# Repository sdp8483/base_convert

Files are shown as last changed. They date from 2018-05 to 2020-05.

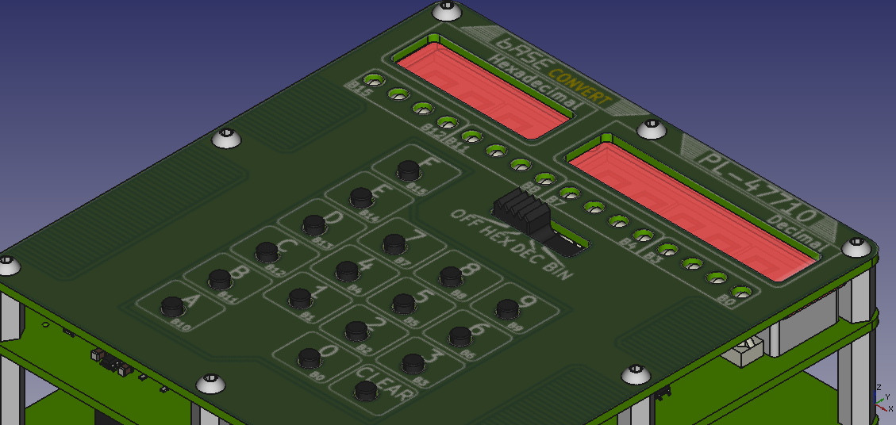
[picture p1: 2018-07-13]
main_pcb/pcb_renders/images/base_convert_assembly_top.png

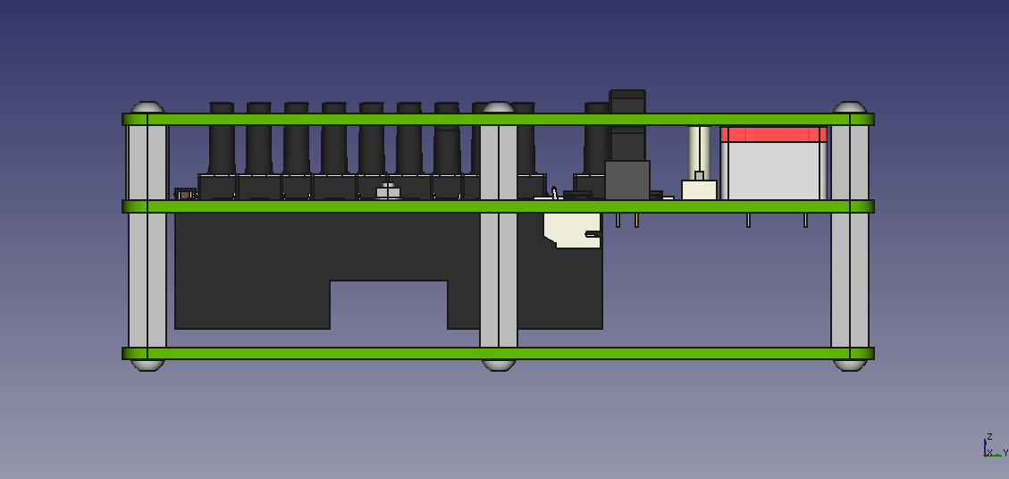
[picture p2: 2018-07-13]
main_pcb/pcb_renders/images/base_convert_assembly_side.png

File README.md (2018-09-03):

# Base Convert Rev A 
## Introduction
Base Convert PL-47710 Rev. A is a simple desk/handheld device to convert between hexadecimal, decimal, and binary. The unit features separate displays for each number base for easy comparison between the three bases. User input is possible using 16 alphanumeric keys and an input mode selector switch. The device is powered by 4 AA alkaline batteries with an estimated 100 hours of battery life.

## Specifications
|Item |Specification |
|:---|:---:|
|Hex Display |4 digit, 7 segment red LED  |
|Decimal Display  |6 digit, 7 segment red LED  |
|Binary Display |16 red LEDs |
|User Input |16 digit alphanumeric keypad|
|Power |4 AA Alkaline |
|Battery Life |100 hrs estimated |
|Width |94mm / 3.7" |
|Height |100mm / 3.94" |
|Thickness |35mm / 1.38" |
|Weight, with 4xAA|275g / 9.65oz |

## Layout
Front Layout Image

1. Hexadecimal Display
2. Decimal Display
3. Binary Display
4. Power and Input Selection Switch
5. Alphanumeric Input Keypad
6. Programming Port (Right Angle Header on Side)

## Installing Batteries
Using a 1.5mm hex bit remove the eight M2.5 button head hex bolts holding the back panel to the unit. Install 4x AA batteries into the battery holder attached to the main PCB. Follow the polarity imprinted on the battery holder. The device does have reverse polarity projection that should project it from damage but it is still advisable to not reverse the polarity of the batteries. Replace the back panel after installing the batteries.

## Use
To turn on the unit slide the selector switch from the OFF position to any of the three input positions. The display will illuminate at the default value of 0.

### To Input Hexadecimal Number
Slide the selector switch to *HEX*. The right most decimal on the hexadecimal display will illuminate when the unit is in hexadecimal input mode. Use the alphanumeric keypad to input a hexadecimal number, all three displays will update after each key press. If the hexadecimal number exceeds 4 digits the left most digit will be dropped to shift in the right most digit. Clearing the display by pressing the *CLEAR* button will set the hexadecimal number to 0.

### To Input Decimal Number
Slide the selector switch to *DEC*. The right most decimal on the decimal display will illuminate when the unit is in decimal input mode. Use the alphanumeric keypad to input a decimal number, all three displays will update after each key press. If the decimal number will exceed 65,535 with the requested key press the device will no longer shift in new decimal digits while in decimal input mode. Clearing the display will set the decimal number to 0.

### To Input Binary Number
Slide the selector switch to *BIN*. There is no indicator on any of the displays to indicate that the unit is in binary input mode. Use the alphanumeric keypad to toggle the bits of the binary number displayed on the binary display, all three displays will update after each key press. Pressing the *CLEAR* button will set the binary number to 0.

## Updating Firmware
It is possible to update the firmware. A TI Launchpad and cable is required. The pin out of the programming header is as follows when looking at the unit from the front.

- 3.3V
- SBWTDIO
- SBWTCK
- GND

External power is required, install 4x AA batteries before updating the firmware and place the selector switch in any of the input positions.

The most current firmware is located here: https://github.com/sdp8483/base_convert/tree/master/firmware/base_convert
CCS 8.x.x or newer is required to update the firmware. Please search online for help using CCS and uploading firmware since this is outside of the scope of this document.

## Future Fixes
- [ ] Silkscreen label of programming interface connections/pins
- [ ] Silkscreen label of power connector + and - pins
- [ ] add space for solder iron around resistor networks
- [ ] battery low indicator in SW, should have HW to do it
- [ ] at 6V the display will not turn off when the PNP are pulled high (cant pull it high enough) 
  Placing a 1k resistor between the base and emitter of each PNP solves the problem but it appears 
  like there is an issue caused with the 3.3V LDO since the voltage to the uC is 4.1V or so not the 3.3V it should be.
  Going to see if 3V for the battery is bright enough and maybe switch to 2AA as battery or go to LiPo in the future.
- [ ] Swap C2 and C4 on PCB so that the correct capacitor is near the correct IC
- [ ] Easy firmware update method --LOW PRIORITY

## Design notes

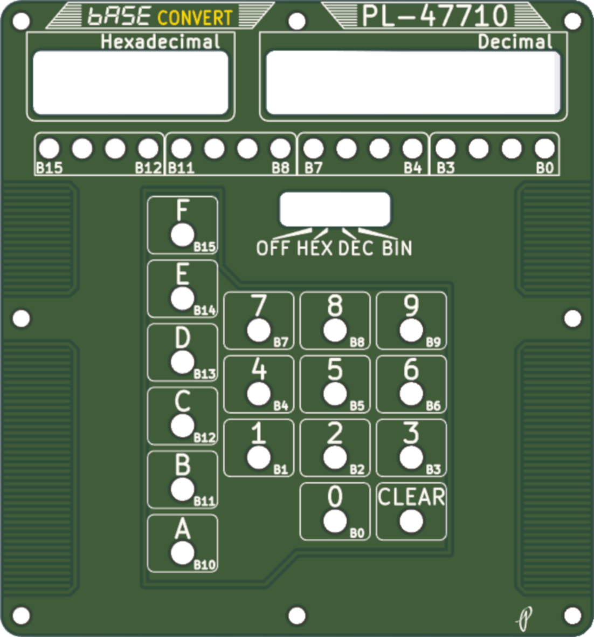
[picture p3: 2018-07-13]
front_panel_pcb/images/front_panel_pcb.png

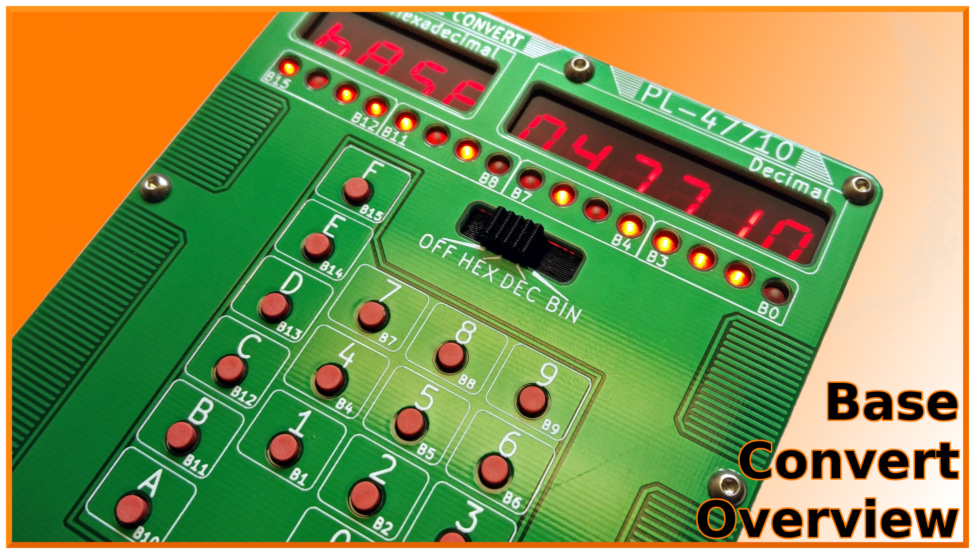
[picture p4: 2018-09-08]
images/Rev A/Tumbnail.jpg

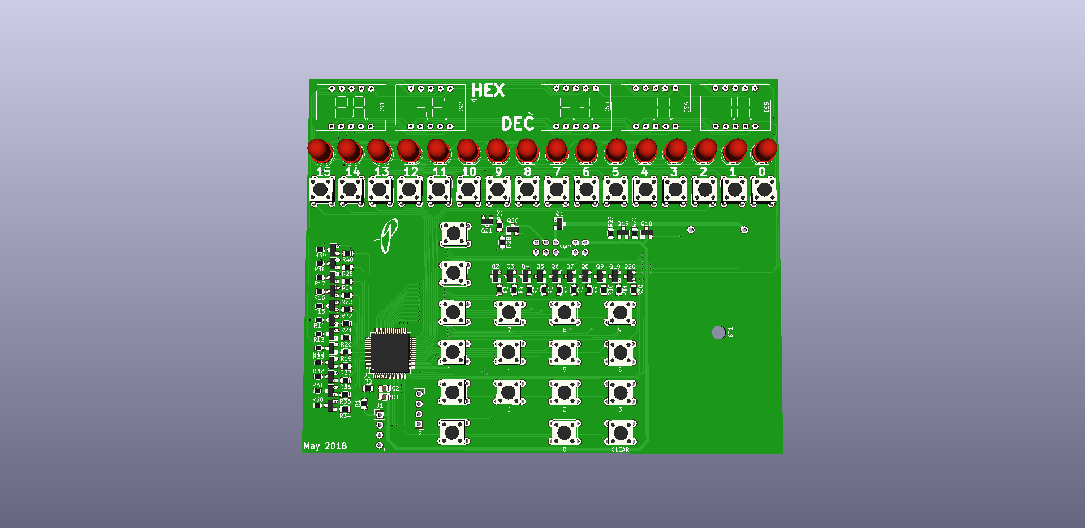
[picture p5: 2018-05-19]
images/base_convert_render2.png

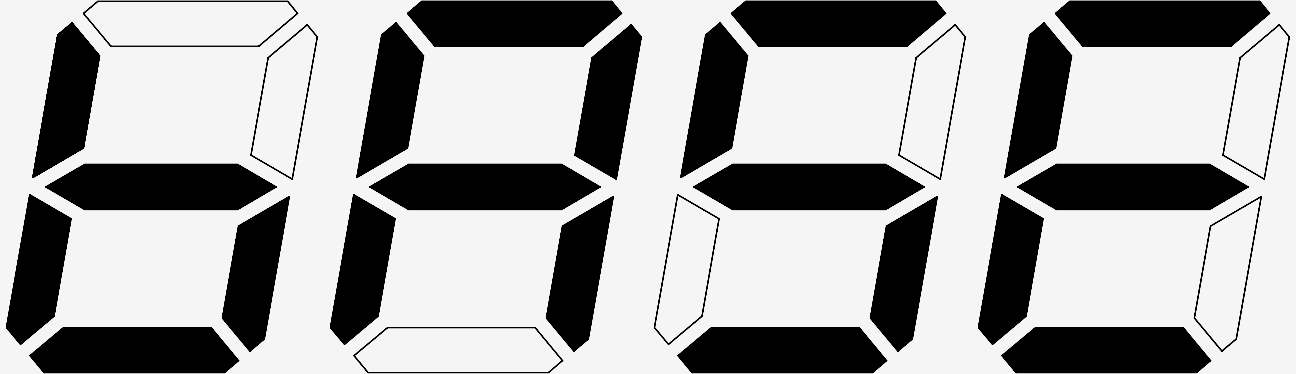
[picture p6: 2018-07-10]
front_panel_pcb/images/silkscreen_artwork/base_in_7seg_font.png

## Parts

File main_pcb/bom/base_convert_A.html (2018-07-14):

Source File | /Users/Sam/Documents/GitHub/base_convert/base_convert.sch
BoM Date | Saturday, July 14, 2018 'AMt' 07:05:44 AM
Schematic Version | A
Schematic Date | 2018-06-20
KiCad Version | Eeschema 4.0.7
Component Groups | 51
Component Count (per PCB) | 88
Fitted Components (per PCB) | 88
Number of PCBs | 1
Total Component Count (for 1 PCBs) | 88
 | Description | Part | References | Value | Footprint | Quantity Per PCB | Datasheet | Manufacture | Package | Mfg Part Number
1 | HOLDER BATT 4-AA CELLS WIRE LDS | BC4AAW | BT1 | 4 Cell AA Battery Clip | BC4AAW | 1 | http://www.memoryprotectiondevices.com/datasheets/BC4AAW-datasheet.pdf | MPD (Memory Protection Devices) | Wire | BC4AAW
2 | CAP CER 0.1UF 16V X7R 0805 | C | C3 | 100nF | C_0805 | 1 | http://www.samsungsem.com/kr/support/product-search/mlcc/CL21B104KOANNNC.jsp | Samsung Electro-Mechanics | 0805 | CL21B104KOANNNC
3 | CAP CER 10UF 6.3V X5R 0805 | C | C2 | 10uF | C_0805 | 1 | http://www.samsungsem.com/kr/support/product-search/mlcc/CL21A106KQFNNNG.jsp | Samsung Electro-Mechanics | 0805 | CL21A106KQFNNNG
4 | CAP CER 1UF 16V X7R 0805 | C | C1 C4 | 1uF | C_0805 | 2 | http://www.samsungsem.com/kr/support/product-search/mlcc/CL21B105KOFNNNG.jsp | Samsung Electro-Mechanics | 0805 | CL21B105KOFNNNG
5 | LED RED CLEAR 0805 SMD | LED | D13 | BIT0 | LED_0805_LightPipe_VLP | 1 | http://katalog.we-online.de/led/datasheet/150080RS75000.pdf | Wurth Electronics Inc. | 0805 | 150080RS75004
6 | LED RED CLEAR 0805 SMD | LED | D9 | BIT1 | LED_0805_LightPipe_VLP | 1 | http://katalog.we-online.de/led/datasheet/150080RS75000.pdf | Wurth Electronics Inc. | 0805 | 150080RS75015
7 | LED RED CLEAR 0805 SMD | LED | D7 | BIT10 | LED_0805_LightPipe_VLP | 1 | http://katalog.we-online.de/led/datasheet/150080RS75000.pdf | Wurth Electronics Inc. | 0805 | 150080RS75013
8 | LED RED CLEAR 0805 SMD | LED | D3 | BIT11 | LED_0805_LightPipe_VLP | 1 | http://katalog.we-online.de/led/datasheet/150080RS75000.pdf | Wurth Electronics Inc. | 0805 | 150080RS75009
9 | LED RED CLEAR 0805 SMD | LED | D16 | BIT12 | LED_0805_LightPipe_VLP | 1 | http://katalog.we-online.de/led/datasheet/150080RS75000.pdf | Wurth Electronics Inc. | 0805 | 150080RS75007
10 | LED RED CLEAR 0805 SMD | LED | D12 | BIT13 | LED_0805_LightPipe_VLP | 1 | http://katalog.we-online.de/led/datasheet/150080RS75000.pdf | Wurth Electronics Inc. | 0805 | 150080RS75003
11 | LED RED CLEAR 0805 SMD | LED | D8 | BIT14 | LED_0805_LightPipe_VLP | 1 | http://katalog.we-online.de/led/datasheet/150080RS75000.pdf | Wurth Electronics Inc. | 0805 | 150080RS75014
12 | LED RED CLEAR 0805 SMD | LED | D4 | BIT15 | LED_0805_LightPipe_VLP | 1 | http://katalog.we-online.de/led/datasheet/150080RS75000.pdf | Wurth Electronics Inc. | 0805 | 150080RS75010
13 | LED RED CLEAR 0805 SMD | LED | D5 | BIT2 | LED_0805_LightPipe_VLP | 1 | http://katalog.we-online.de/led/datasheet/150080RS75000.pdf | Wurth Electronics Inc. | 0805 | 150080RS75011
14 | LED RED CLEAR 0805 SMD | LED | D1 | BIT3 | LED_0805_LightPipe_VLP | 1 | http://katalog.we-online.de/led/datasheet/150080RS75000.pdf | Wurth Electronics Inc. | 0805 | 150080RS75000
15 | LED RED CLEAR 0805 SMD | LED | D14 | BIT4 | LED_0805_LightPipe_VLP | 1 | http://katalog.we-online.de/led/datasheet/150080RS75000.pdf | Wurth Electronics Inc. | 0805 | 150080RS75005
16 | LED RED CLEAR 0805 SMD | LED | D10 | BIT5 | LED_0805_LightPipe_VLP | 1 | http://katalog.we-online.de/led/datasheet/150080RS75000.pdf | Wurth Electronics Inc. | 0805 | 150080RS75001
17 | LED RED CLEAR 0805 SMD | LED | D6 | BIT6 | LED_0805_LightPipe_VLP | 1 | http://katalog.we-online.de/led/datasheet/150080RS75000.pdf | Wurth Electronics Inc. | 0805 | 150080RS75012
18 | LED RED CLEAR 0805 SMD | LED | D2 | BIT7 | LED_0805_LightPipe_VLP | 1 | http://katalog.we-online.de/led/datasheet/150080RS75000.pdf | Wurth Electronics Inc. | 0805 | 150080RS75008
19 | LED RED CLEAR 0805 SMD | LED | D15 | BIT8 | LED_0805_LightPipe_VLP | 1 | http://katalog.we-online.de/led/datasheet/150080RS75000.pdf | Wurth Electronics Inc. | 0805 | 150080RS75006
20 | LED RED CLEAR 0805 SMD | LED | D11 | BIT9 | LED_0805_LightPipe_VLP | 1 | http://katalog.we-online.de/led/datasheet/150080RS75000.pdf | Wurth Electronics Inc. | 0805 | 150080RS75002
21 | LED 7-SEG 2DIGIT RED LC 0.28" CA | LTD-2601WC | DS1 DS2 DS3 DS4 DS5 | LTD-2601WC | Display_Lite-On_LTD-2601WC | 5 | https://media.digikey.com/pdf/Data%20Sheets/Lite-On%20PDFs/LTD-2601WC_11-14-00.pdf | Lite-On Inc. | 10-DIP | LTD-2601WC
22 |  | Conn_01x04 | J1 | ISP | Pin_Header_Straight_1x04_Pitch2.54mm | 1
23 | CONN HEADER PH SIDE 2POS 2MM | Conn_01x02 | J3 | Vin | JST_PH_S2B-PH-K_02x2.00mm_Angled | 1 | http://www.jst-mfg.com/product/pdf/eng/ePH.pdf | JST Sales America Inc. | 2.0mm Pin | S2B-PH-K-S(LF)(SN)
24 | RES SMD 0 OHM JUMPER 1/4W 1206 | Jumper_NO_Small | JP1 | VTARG_EN | R_1206 | 1 | http://www.yageo.com/documents/recent/PYu-RC_Group_51_RoHS_L_9.pdf | Yageo | 1206 | RC1206JR-070RL
25 | TRANSISTOR, NPN, 40V, 0.2A, 100A | Q_NPN_BEC | Q6 Q7 Q8 Q9 Q20 Q21 Q22 Q23 Q24 Q25 Q26 Q27 | Q_NPN_BEC | SOT-23 | 12 | http://www.taiwansemi.com/products/datasheet/MMBT3904L_A15.pdf | Taiwan Semiconductor Corporation | SOT-23 | MMBT3904L RFG
26 | MOSFET P-CH 20V 5.3A SOT-23 | Q_PMOS_GSD | Q1 | Q_PMOS_GSD | SOT-23 | 1 | http://www.vishay.com/docs/64004/si2323dds.pdf | Vishay Siliconix | SOT-23 | SI2323DDS-T1-GE3
27 | TRANS PNP 40V 0.2A SOT23 | Q_PNP_BEC | Q2 Q3 Q4 Q5 Q10 Q11 Q12 Q13 Q14 Q15 Q16 Q17 Q18 Q19 | Q_PNP_BEC | SOT-23 | 14 | https://assets.nexperia.com/documents/data-sheet/PMBT3906.pdf | Nexperia USA Inc. | SOT-23 | PMBT3906,235
28 | RES SMD 102K OHM 1% 1/10W 0603 | R | R1 | 102k | R_0603 | 1 | http://rohmfs.rohm.com/en/products/databook/datasheet/passive/resistor/chip_resistor/mcr_g.pdf | Rohm Semiconductor | 0603 | MCR03ERTF1023
29 | RES SMD 25.5K OHM 1% 1/10W 0603 | R | R2 | 25.5k | R_0603 | 1 | http://rohmfs.rohm.com/en/products/databook/datasheet/passive/resistor/chip_resistor/mcr_g.pdf | Rohm Semiconductor | 0603 | MCR03ERTF2552
30 | RES ARRAY 4 RES 150 OHM 1206 | R_Pack04 | RN2 RN7 RN8 | 150 | R_Array_Convex_4x1206 | 3 | http://rohmfs.rohm.com/en/products/databook/datasheet/passive/resistor/chip_resistor_network/mnr_g.pdf | Rohm Semiconductor | 1206 | MNR14ERAPJ151
31 | RES ARRAY 4 RES 4.7K OHM 1206 | R_Pack04 | RN1 RN3 RN4 RN5 RN6 RN9 RN10 | 4.7k | R_Array_Convex_4x1206 | 7 | https://www.seielect.com/Catalog/SEI-RAVF.pdf | Stackpole Electronics Inc. | 1206 | RAVF164DJT4K70
32 | SWITCH TACTILE SPST-NO 0.05A 12V | SW_Push_Dual2 | SW9 | 0 | CK_PTS645_6mm_SMD | 1 | https://www.ckswitches.com/media/1471/pts645.pdf | C&K | SMT | PTS645SK13SMTR92LFS
33 | SWITCH TACTILE SPST-NO 0.05A 12V | SW_Push_Dual2 | SW10 | 1 | CK_PTS645_6mm_SMD | 1 | https://www.ckswitches.com/media/1471/pts645.pdf | C&K | SMT | PTS645SK13SMTR92LFS
34 | SWITCH TACTILE SPST-NO 0.05A 12V | SW_Push_Dual2 | SW6 | 2 | CK_PTS645_6mm_SMD | 1 | https://www.ckswitches.com/media/1471/pts645.pdf | C&K | SMT | PTS645SK13SMTR92LFS
35 | SWITCH TACTILE SPST-NO 0.05A 12V | SW_Push_Dual2 | SW2 | 3 | CK_PTS645_6mm_SMD | 1 | https://www.ckswitches.com/media/1471/pts645.pdf | C&K | SMT | PTS645SK13SMTR92LFS
36 | SWITCH TACTILE SPST-NO 0.05A 12V | SW_Push_Dual2 | SW11 | 4 | CK_PTS645_6mm_SMD | 1 | https://www.ckswitches.com/media/1471/pts645.pdf | C&K | SMT | PTS645SK13SMTR92LFS
37 | SWITCH TACTILE SPST-NO 0.05A 12V | SW_Push_Dual2 | SW7 | 5 | CK_PTS645_6mm_SMD | 1 | https://www.ckswitches.com/media/1471/pts645.pdf | C&K | SMT | PTS645SK13SMTR92LFS
38 | SWITCH TACTILE SPST-NO 0.05A 12V | SW_Push_Dual2 | SW3 | 6 | CK_PTS645_6mm_SMD | 1 | https://www.ckswitches.com/media/1471/pts645.pdf | C&K | SMT | PTS645SK13SMTR92LFS
39 | SWITCH TACTILE SPST-NO 0.05A 12V | SW_Push_Dual2 | SW12 | 7 | CK_PTS645_6mm_SMD | 1 | https://www.ckswitches.com/media/1471/pts645.pdf | C&K | SMT | PTS645SK13SMTR92LFS
40 | SWITCH TACTILE SPST-NO 0.05A 12V | SW_Push_Dual2 | SW8 | 8 | CK_PTS645_6mm_SMD | 1 | https://www.ckswitches.com/media/1471/pts645.pdf | C&K | SMT | PTS645SK13SMTR92LFS
41 | SWITCH TACTILE SPST-NO 0.05A 12V | SW_Push_Dual2 | SW4 | 9 | CK_PTS645_6mm_SMD | 1 | https://www.ckswitches.com/media/1471/pts645.pdf | C&K | SMT | PTS645SK13SMTR92LFS
42 | SWITCH TACTILE SPST-NO 0.05A 12V | SW_Push_Dual2 | SW13 | A | CK_PTS645_6mm_SMD | 1 | https://www.ckswitches.com/media/1471/pts645.pdf | C&K | SMT | PTS645SK13SMTR92LFS
43 | SWITCH TACTILE SPST-NO 0.05A 12V | SW_Push_Dual2 | SW15 | B | CK_PTS645_6mm_SMD | 1 | https://www.ckswitches.com/media/1471/pts645.pdf | C&K | SMT | PTS645SK13SMTR92LFS
44 | SWITCH TACTILE SPST-NO 0.05A 12V | SW_Push_Dual2 | SW16 | C | CK_PTS645_6mm_SMD | 1 | https://www.ckswitches.com/media/1471/pts645.pdf | C&K | SMT | PTS645SK13SMTR92LFS
45 | SWITCH TACTILE SPST-NO 0.05A 12V | SW_Push_Dual2 | SW14 | CLEAR | CK_PTS645_6mm_SMD | 1 | https://www.ckswitches.com/media/1471/pts645.pdf | C&K | SMT | PTS645SK13SMTR92LFS
46 | SWITCH TACTILE SPST-NO 0.05A 12V | SW_Push_Dual2 | SW17 | D | CK_PTS645_6mm_SMD | 1 | https://www.ckswitches.com/media/1471/pts645.pdf | C&K | SMT | PTS645SK13SMTR92LFS
47 | SWITCH TACTILE SPST-NO 0.05A 12V | SW_Push_Dual2 | SW18 | E | CK_PTS645_6mm_SMD | 1 | https://www.ckswitches.com/media/1471/pts645.pdf | C&K | SMT | PTS645SK13SMTR92LFS
48 | SWITCH TACTILE SPST-NO 0.05A 12V | SW_Push_Dual2 | SW5 | F | CK_PTS645_6mm_SMD | 1 | https://www.ckswitches.com/media/1471/pts645.pdf | C&K | SMT | PTS645SK13SMTR92LFS
49 | SWITCH SLIDE DP4T 300MA 30V | SS-24E06-TG5P | SW1 | SELECT | DP4T_SS-24E06-TG5P | 1 | https://media.digikey.com/pdf/Data%20Sheets/C&K/SS-24E06-TG_5_(P).pdf | C&K | PC Pin | SS-24E06-TG 5 (P)
50 | IC REG LINEAR 3.3V 150MA SOT23-5 | MIC5317 | U1 | MIC5317-3.3YM5-TR | SOT-23-5 | 1 | http://www.microchip.com/mymicrochip/filehandler.aspx?ddocname=en579427 | Microchip Technology | SOT23-5 | MIC5317-3.3YM5-TR
51 | IC MCU 16BIT 15.5KB FRAM 64LQFP | MSP430FR2033IPMR | U2 | MSP430FR2033IPMR | LQFP-64_10x10mm_Pitch0.5mm | 1 | http://www.ti.com/lit/ds/symlink/msp430fr2032.pdf | Texas Instruments | 64LQFP | MSP430FR2033IPMR

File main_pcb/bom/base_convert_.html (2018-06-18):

Source File | C:/Users/Sam/Dropbox/KiCAD/projects/base_convert/base_convert.sch
BoM Date | 6/18/2018 7:24:17 PM
Schematic Version
Schematic Date
KiCad Version | Eeschema 4.0.7
Component Groups | 51
Component Count (per PCB) | 116
Fitted Components (per PCB) | 116
Number of PCBs | 1
Total Component Count (for 1 PCBs) | 116
 | Description | Part | References | Value | Footprint | Quantity Per PCB | Datasheet | Manufacture | Package | Mfg Part Number
1 | HOLDER BATT 4-AA CELLS PC MNT | Battery | BT1 | 4 Cell AA Battery Holder | BC4AAPC | 1 | http://www.memoryprotectiondevices.com/datasheets/BC4AAPC-datasheet.pdf | MPD (Memory Protection Devices) | PC Pin | BC4AAPC
2 | CAP CER 0.1UF 16V X7R 0805 | C | C2 | 100nF | C_0805 | 1 | http://www.samsungsem.com/kr/support/product-search/mlcc/CL21B104KOANNNC.jsp | Samsung Electro-Mechanics | 0805 | CL21B104KOANNNC
3 | CAP CER 10UF 6.3V X5R 0805 | C | C1 | 10uF | C_0805 | 1 | http://www.samsungsem.com/kr/support/product-search/mlcc/CL21A106KQFNNNG.jsp | Samsung Electro-Mechanics | 0805 | CL21A106KQFNNNG
4 | CAP CER 1UF 16V X7R 0805 | C | C3 C4 | 1uF | C_0805 | 2 | http://www.samsungsem.com/kr/support/product-search/mlcc/CL21B105KOFNNNG.jsp | Samsung Electro-Mechanics | 0805 | CL21B105KOFNNNG
5 | LED RED CLEAR 0805 SMD | LED | D13 | BIT0 | LED_0805_LightPipe_VLP | 1 | http://katalog.we-online.de/led/datasheet/150080RS75000.pdf | Wurth Electronics Inc. | 0805 | 150080RS75004
6 | LED RED CLEAR 0805 SMD | LED | D9 | BIT1 | LED_0805_LightPipe_VLP | 1 | http://katalog.we-online.de/led/datasheet/150080RS75000.pdf | Wurth Electronics Inc. | 0805 | 150080RS75015
7 | LED RED CLEAR 0805 SMD | LED | D7 | BIT10 | LED_0805_LightPipe_VLP | 1 | http://katalog.we-online.de/led/datasheet/150080RS75000.pdf | Wurth Electronics Inc. | 0805 | 150080RS75013
8 | LED RED CLEAR 0805 SMD | LED | D3 | BIT11 | LED_0805_LightPipe_VLP | 1 | http://katalog.we-online.de/led/datasheet/150080RS75000.pdf | Wurth Electronics Inc. | 0805 | 150080RS75009
9 | LED RED CLEAR 0805 SMD | LED | D16 | BIT12 | LED_0805_LightPipe_VLP | 1 | http://katalog.we-online.de/led/datasheet/150080RS75000.pdf | Wurth Electronics Inc. | 0805 | 150080RS75007
10 | LED RED CLEAR 0805 SMD | LED | D12 | BIT13 | LED_0805_LightPipe_VLP | 1 | http://katalog.we-online.de/led/datasheet/150080RS75000.pdf | Wurth Electronics Inc. | 0805 | 150080RS75003
11 | LED RED CLEAR 0805 SMD | LED | D8 | BIT14 | LED_0805_LightPipe_VLP | 1 | http://katalog.we-online.de/led/datasheet/150080RS75000.pdf | Wurth Electronics Inc. | 0805 | 150080RS75014
12 | LED RED CLEAR 0805 SMD | LED | D4 | BIT15 | LED_0805_LightPipe_VLP | 1 | http://katalog.we-online.de/led/datasheet/150080RS75000.pdf | Wurth Electronics Inc. | 0805 | 150080RS75010
13 | LED RED CLEAR 0805 SMD | LED | D5 | BIT2 | LED_0805_LightPipe_VLP | 1 | http://katalog.we-online.de/led/datasheet/150080RS75000.pdf | Wurth Electronics Inc. | 0805 | 150080RS75011
14 | LED RED CLEAR 0805 SMD | LED | D1 | BIT3 | LED_0805_LightPipe_VLP | 1 | http://katalog.we-online.de/led/datasheet/150080RS75000.pdf | Wurth Electronics Inc. | 0805 | 150080RS75000
15 | LED RED CLEAR 0805 SMD | LED | D14 | BIT4 | LED_0805_LightPipe_VLP | 1 | http://katalog.we-online.de/led/datasheet/150080RS75000.pdf | Wurth Electronics Inc. | 0805 | 150080RS75005
16 | LED RED CLEAR 0805 SMD | LED | D10 | BIT5 | LED_0805_LightPipe_VLP | 1 | http://katalog.we-online.de/led/datasheet/150080RS75000.pdf | Wurth Electronics Inc. | 0805 | 150080RS75001
17 | LED RED CLEAR 0805 SMD | LED | D6 | BIT6 | LED_0805_LightPipe_VLP | 1 | http://katalog.we-online.de/led/datasheet/150080RS75000.pdf | Wurth Electronics Inc. | 0805 | 150080RS75012
18 | LED RED CLEAR 0805 SMD | LED | D2 | BIT7 | LED_0805_LightPipe_VLP | 1 | http://katalog.we-online.de/led/datasheet/150080RS75000.pdf | Wurth Electronics Inc. | 0805 | 150080RS75008
19 | LED RED CLEAR 0805 SMD | LED | D15 | BIT8 | LED_0805_LightPipe_VLP | 1 | http://katalog.we-online.de/led/datasheet/150080RS75000.pdf | Wurth Electronics Inc. | 0805 | 150080RS75006
20 | LED RED CLEAR 0805 SMD | LED | D11 | BIT9 | LED_0805_LightPipe_VLP | 1 | http://katalog.we-online.de/led/datasheet/150080RS75000.pdf | Wurth Electronics Inc. | 0805 | 150080RS75002
21 | LED 7-SEG .40" 2DGT SUPER RED CA | LTD-4608JR | DS1 DS2 DS3 DS4 DS5 | LTD-4608JR | Display_Lite-On_LTD-4608JR | 5 | https://media.digikey.com/pdf/Data%20Sheets/Lite-On%20PDFs/LTD-4608JR.pdf | Lite-On Inc. | 10-DIP | LTD-4608JR
22 |  | Conn_01x10 | J2 | DEBUG | Pin_Header_Straight_1x10_Pitch2.54mm | 1
23 |  | Conn_01x04 | J1 | ISP | Pin_Header_Straight_1x04_Pitch2.54mm | 1
24 | RES SMD 0 OHM JUMPER 1/4W 1206 | Jumper_NO_Small | JP1 | VTARG_EN | R_1206 | 1 | http://www.yageo.com/documents/recent/PYu-RC_Group_51_RoHS_L_9.pdf | Yageo | 1206 | RC1206JR-070RL
25 | TRANSISTOR, NPN, 40V, 0.2A, 100A | Q_NPN_BEC | Q11 Q12 Q13 Q14 Q15 Q16 Q17 Q22 Q23 Q24 Q25 Q27 | Q_NPN_BEC | SOT-23 | 12 | http://www.taiwansemi.com/products/datasheet/MMBT3904L_A15.pdf | Taiwan Semiconductor Corporation | SOT-23 | MMBT3904L RFG
26 | MOSFET P-CH 20V 5.3A SOT-23 | Q_PMOS_GSD | Q1 | Q_PMOS_GSD | SOT-23 | 1 | http://www.vishay.com/docs/64004/si2323dds.pdf | Vishay Siliconix | SOT-23 | SI2323DDS-T1-GE3
27 | TRANS PNP 40V 0.2A SOT25 | Q_PNP_BEC | Q2 Q3 Q4 Q5 Q6 Q7 Q8 Q9 Q10 Q18 Q19 Q20 Q21 Q26 | Q_PNP_BEC | SOT-23 | 14 | https://assets.nexperia.com/documents/data-sheet/PMBT3906.pdf | Nexperia USA Inc. | SOT-23 | PMBT3906,237 PMBT3906,235 PMBT3906,236 PMBT3906,238 PMBT3906,239 PMBT3906,240 PMBT3906,241
28 | RES SMD 102K OHM 1% 1/10W 0603 | R | R1 | 102k | R_0603 | 1 | http://rohmfs.rohm.com/en/products/databook/datasheet/passive/resistor/chip_resistor/mcr_g.pdf | Rohm Semiconductor | 0603 | MCR03ERTF1023
29 | RES SMD 150 OHM 5% 1/10W 0603 | R | R12 R13 R14 R15 R16 R17 R18 R30 R31 R32 R33 R39 | 150 | R_0603 | 12 | http://www.yageo.com/documents/recent/PYu-RC_Group_51_RoHS_L_9.pdf | Yageo | 0603 | RC0603JR-07150RL
30 | RES SMD 25.5K OHM 1% 1/10W 0603 | R | R2 | 25.5k | R_0603 | 1 | http://rohmfs.rohm.com/en/products/databook/datasheet/passive/resistor/chip_resistor/mcr_g.pdf | Rohm Semiconductor | 0603 | MCR03ERTF2552
31 | RES SMD 4.7K OHM 5% 1/10W 0603 | R | R3 R4 R5 R6 R7 R8 R9 R10 R11 R19 R20 R21 R22 R23 R24 R25 R26 R27 R28 R29 R34 R35 R36 R37 R38 R40 | 4.7k | R_0603 | 26 | http://industrial.panasonic.com/www-cgi/jvcr13pz.cgi?E+PZ+3+AOA0001+ERJ3GEYJ472V+7+WW | Panasonic Electronic Components | 0603 | ERJ-3GEYJ472V
32 | SWITCH TACTILE SPST-NO 0.05A 12V | SW_Push_Dual2 | SW19 | 0 | CK_PTS645_6mm_SMD | 1 | https://www.ckswitches.com/media/1471/pts645.pdf | C&K | SMT | PTS645SK95SMTR92LFS
33 | SWITCH TACTILE SPST-NO 0.05A 12V | SW_Push_Dual2 | SW23 | 1 | CK_PTS645_6mm_SMD | 1 | https://www.ckswitches.com/media/1471/pts645.pdf | C&K | SMT | PTS645SK95SMTR92LFS
34 | SWITCH TACTILE SPST-NO 0.05A 12V | SW_Push_Dual2 | SW27 | 2 | CK_PTS645_6mm_SMD | 1 | https://www.ckswitches.com/media/1471/pts645.pdf | C&K | SMT | PTS645SK95SMTR92LFS
35 | SWITCH TACTILE SPST-NO 0.05A 12V | SW_Push_Dual2 | SW31 | 3 | CK_PTS645_6mm_SMD | 1 | https://www.ckswitches.com/media/1471/pts645.pdf | C&K | SMT | PTS645SK95SMTR92LFS
36 | SWITCH TACTILE SPST-NO 0.05A 12V | SW_Push_Dual2 | SW20 | 4 | CK_PTS645_6mm_SMD | 1 | https://www.ckswitches.com/media/1471/pts645.pdf | C&K | SMT | PTS645SK95SMTR92LFS
37 | SWITCH TACTILE SPST-NO 0.05A 12V | SW_Push_Dual2 | SW24 | 5 | CK_PTS645_6mm_SMD | 1 | https://www.ckswitches.com/media/1471/pts645.pdf | C&K | SMT | PTS645SK95SMTR92LFS
38 | SWITCH TACTILE SPST-NO 0.05A 12V | SW_Push_Dual2 | SW28 | 6 | CK_PTS645_6mm_SMD | 1 | https://www.ckswitches.com/media/1471/pts645.pdf | C&K | SMT | PTS645SK95SMTR92LFS
39 | SWITCH TACTILE SPST-NO 0.05A 12V | SW_Push_Dual2 | SW32 | 7 | CK_PTS645_6mm_SMD | 1 | https://www.ckswitches.com/media/1471/pts645.pdf | C&K | SMT | PTS645SK95SMTR92LFS
40 | SWITCH TACTILE SPST-NO 0.05A 12V | SW_Push_Dual2 | SW21 | 8 | CK_PTS645_6mm_SMD | 1 | https://www.ckswitches.com/media/1471/pts645.pdf | C&K | SMT | PTS645SK95SMTR92LFS
41 | SWITCH TACTILE SPST-NO 0.05A 12V | SW_Push_Dual2 | SW25 | 9 | CK_PTS645_6mm_SMD | 1 | https://www.ckswitches.com/media/1471/pts645.pdf | C&K | SMT | PTS645SK95SMTR92LFS
42 | SWITCH TACTILE SPST-NO 0.05A 12V | SW_Push_Dual2 | SW29 | A | CK_PTS645_6mm_SMD | 1 | https://www.ckswitches.com/media/1471/pts645.pdf | C&K | SMT | PTS645SK95SMTR92LFS
43 | SWITCH TACTILE SPST-NO 0.05A 12V | SW_Push_Dual2 | SW33 | B | CK_PTS645_6mm_SMD | 1 | https://www.ckswitches.com/media/1471/pts645.pdf | C&K | SMT | PTS645SK95SMTR92LFS
44 | SWITCH TACTILE SPST-NO 0.05A 12V | SW_Push_Dual2 | SW22 | C | CK_PTS645_6mm_SMD | 1 | https://www.ckswitches.com/media/1471/pts645.pdf | C&K | SMT | PTS645SK95SMTR92LFS
45 | SWITCH TACTILE SPST-NO 0.05A 12V | SW_Push_Dual2 | SW1 | CLEAR | CK_PTS645_6mm_SMD | 1 | https://www.ckswitches.com/media/1471/pts645.pdf | C&K | SMT | PTS645SK95SMTR92LFS
46 | SWITCH TACTILE SPST-NO 0.05A 12V | SW_Push_Dual2 | SW26 | D | CK_PTS645_6mm_SMD | 1 | https://www.ckswitches.com/media/1471/pts645.pdf | C&K | SMT | PTS645SK95SMTR92LFS
47 | SWITCH TACTILE SPST-NO 0.05A 12V | SW_Push_Dual2 | SW30 | E | CK_PTS645_6mm_SMD | 1 | https://www.ckswitches.com/media/1471/pts645.pdf | C&K | SMT | PTS645SK95SMTR92LFS
48 | SWITCH TACTILE SPST-NO 0.05A 12V | SW_Push_Dual2 | SW34 | F | CK_PTS645_6mm_SMD | 1 | https://www.ckswitches.com/media/1471/pts645.pdf | C&K | SMT | PTS645SK95SMTR92LFS
49 | SWITCH SLIDE DP4T 300MA 30V | SS-24E06-TG5P | SW2 | SELECT | DP4T_SS-24E06-TG5P | 1 | https://media.digikey.com/pdf/Data%20Sheets/C&K/SS-24E06-TG_5_(P).pdf | C&K | PC Pin | SS-24E06-TG 5 (P)
50 | IC REG LINEAR 3.3V 150MA SOT23-5 | MIC5317 | U1 | MIC5317-3.3YM5-TR | SOT-23-5 | 1 | http://www.microchip.com/mymicrochip/filehandler.aspx?ddocname=en579427 | Microchip Technology | SOT23-5 | MIC5317-3.3YM5-TR
51 | IC MCU 16BIT 15.5KB FRAM 64LQFP | MSP430FR2033IPMR | U2 | MSP430FR2033IPMR | LQFP-64_10x10mm_Pitch0.5mm | 1 | http://www.ti.com/lit/ds/symlink/msp430fr2032.pdf | Texas Instruments | 64LQFP | MSP430FR2033IPMR

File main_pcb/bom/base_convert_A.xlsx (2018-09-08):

Description | References | Quantity Per PCB | Manufacture | Mfg Part Number | Supplier | Supplier Part Number | Purchased Qty | Price | Cost Per Unit | Cost Per PCB
HOLDER BATT 4-AA CELLS WIRE LDS | BT1 | 1 | MPD (Memory Protection Devices) | BC4AAW | DigiKey | BC4AAW-ND (https://www.digikey.com/product-detail/en/mpd-memory-protection-devices/BC4AAW/BC4AAW-ND/66733) | 6 | $10.98 | $1.83 | $1.83
CAP CER 0.1UF 16V X7R 0805 | C3 | 1 | Samsung Electro-Mechanics | CL21B104KOANNNC | DigiKey | 1276-2448-1-ND (https://www.digikey.com/product-detail/en/samsung-electro-mechanics/CL21B104KOANNNC/1276-2448-1-ND/3890534) | 500 | $4.43 | $0.01 | $0.01
CAP CER 10UF 6.3V X5R 0805 | C2 | 1 | Samsung Electro-Mechanics | CL21A106MQFNNNE | DigiKey | 1276-1298-1-ND (https://www.digikey.com/product-detail/en/samsung-electro-mechanics/CL21A106MQFNNNE/1276-1298-1-ND/3889384) | 100 | $4.62 | $0.05 | $0.05
CAP CER 1UF 16V X7R 0805 | C1 C4 | 2 | Samsung Electro-Mechanics | CL21B105KOFNNNG | DigiKey | 1276-6471-1-ND (https://www.digikey.com/product-detail/en/samsung-electro-mechanics/CL21B105KOFNNNG/1276-6471-1-ND/5958099) | 500 | $7.39 | $0.01 | $0.03
LED RED CLEAR 0805 SMD | D1-D16 | 16 | Wurth Electronics Inc. | 150080RS75000 | DigiKey | 732-4984-1-ND (https://www.digikey.com/product-detail/en/wurth-electronics-inc/150080RS75000/732-4984-1-ND/4489916) | 160 | $21.92 | $0.14 | $2.19
LED 7-SEG 2DIGIT RED LC 0.28" CA | DS1 DS2 DS3 DS4 DS5 | 5 | Lite-On Inc. | LTD-2601WC | DigiKey | 160-2244-ND (https://www.digikey.com/product-detail/en/lite-on-inc/LTD-2601WC/160-2244-ND/3199017) | 35 | $53.10 | $1.52 | $7.59
4POS SIL HORIZONTAL PIN HEADER | J1 | 1 | Harwin Inc. | M20-9750446 | DigiKey | 952-1965-ND | 1 | $0.18 | $0.18 | $0.18
CONN HEADER PH SIDE 2POS 2MM | J3 | 1 | JST Sales America Inc. | S2B-PH-K-S(LF)(SN) | DigiKey | 455-1719-ND (https://www.digikey.com/product-detail/en/jst-sales-america-inc/S2B-PH-K-S(LF)(SN)/455-1719-ND/926626) | 10 | $1.61 | $0.16 | $0.16
CONN HOUSING PH 2POS 2MM WHITE |  | 1 | JST Sales America Inc. | PHR-2 | DigiKey | 455-1165-ND (https://www.digikey.com/product-detail/en/jst-sales-america-inc/PHR-2/455-1165-ND/608607) | 10 | $0.78 | $0.08 | $0.08
CONN TERMINAL 28-24AWG TIN |  | 2 | JST Sales America Inc. | SPH-002T-P0.5L | DigiKey | 455-2148-1-ND (https://www.digikey.com/product-detail/en/jst-sales-america-inc/SPH-002T-P0.5L/455-2148-1-ND/1634657) | 100 | $2.99 | $0.03 | $0.06
RES SMD 0 OHM JUMPER 1/4W 1206 | JP1 | 0 | Yageo | RC1206JR-070RL | DigiKey | 311-0.0ERCT-ND (https://www.digikey.com/product-detail/en/yageo/RC1206JR-070RL/311-0.0ERCT-ND/732131) | 1000 | $4.35 | $0.00435 | $0.00
TRANSISTOR, NPN, 40V, 0.2A, 100A | Q6 Q7 Q8 Q9 Q20 Q21 Q22 Q23 Q24 Q25 Q26 Q27 | 12 | Taiwan Semiconductor Corporation | MMBT3904L RFG | DigiKey | MMBT3904LRFGCT-ND (https://www.digikey.com/product-detail/en/taiwan-semiconductor-corporation/MMBT3904L-RFG/MMBT3904LRFGCT-ND/7357839) | 200 | $10.14 | $0.05 | $0.61
MOSFET P-CH 20V 5.3A SOT-23 | Q1 | 1 | Vishay Siliconix | SI2323DDS-T1-GE3 | DigiKey | SI2323DDS-T1-GE3CT-ND (https://www.digikey.com/product-detail/en/vishay-siliconix/SI2323DDS-T1-GE3/SI2323DDS-T1-GE3CT-ND/4142086) | 10 | $6.05 | $0.60 | $0.60
TRANS PREBIAS PNP 250MW TO236AB | Q2 Q3 Q4 Q5 Q10 Q11 Q12 Q13 Q14 Q15 Q16 Q17 Q18 Q19 | 14 | Nexperia USA Inc. | PDTA123ET,215 | DigiKey | 1727-1691-1-ND (https://www.digikey.com/product-detail/en/nexperia-usa-inc/PDTA123ET,215/1727-1691-1-ND/4581217) | 20 | $3.36 | $0.17 | $2.35
RES SMD 102K OHM 1% 1/10W 0603 | R1 | 1 | Rohm Semiconductor | MCR03ERTF1023 | DigiKey | RHM102KCFCT-ND (https://www.digikey.com/product-detail/en/rohm-semiconductor/MCR03ERTF1023/RHM102KCFCT-ND/4083896) | 2500 | $4.24 | $0.001696 | $0.001696
RES SMD 25.5K OHM 1% 1/10W 0603 | R2 | 1 | Rohm Semiconductor | MCR03ERTF2552 | DigiKey | RHM25.5KCFCT-ND (https://www.digikey.com/product-detail/en/rohm-semiconductor/MCR03ERTF2552/RHM25.5KCFCT-ND/4084087) | 408 | $1.75 | $0.004289215686 | $0.004289215686
RES ARRAY 4 RES 150 OHM 2012 | RN2 RN7 RN8 | 3 | Rohm Semiconductor | MNR34J5ABJ151 | DigiKey | MNR34151CT-ND (https://www.digikey.com/product-detail/en/rohm-semiconductor/MNR34J5ABJ151/MNR34151CT-ND/657596) | 30 | $5.39 | $0.18 | $0.54
RES ARRAY 4 RES 5.6K OHM 2012 | RN3 RN9 RN10 | 3 | Rohm Semiconductor | MNR34J5ABJ562 | DigiKey | MNR34562CT-ND (https://www.digikey.com/product-detail/en/rohm-semiconductor/MNR34J5ABJ562/MNR34562CT-ND/657638) | 50 | $6.51 | $0.13 | $0.39
RES ARRAY 4 RES 10K OHM 2012 | RN1 RN4 RN5 RN6 | 4 | Yageo | YC324-JK-0710KL | DigiKey | YC324J-10KCT-ND (https://www.digikey.com/product-detail/en/yageo/YC324-JK-0710KL/YC324J-10KCT-ND/1005865) | 50 | $7.97 | $0.16 | $0.64
SWITCH TACTILE SPST-NO 0.05A 12V | SW2-SW18 | 17 | C&K | PTS645SK13SMTR92LFS | DigiKey | CKN10817CT-ND (https://www.digikey.com/product-detail/en/c-k/PTS645SK13SMTR92LFS/CKN10817CT-ND/7056128) | 118 | $34.00 | $0.29 | $4.90
SWITCH SLIDE DP4T 300MA 30V | SW1 | 1 | C&K | SS-24E06-TG 5 (P) | DigiKey | CKN10394-ND (https://www.digikey.com/product-detail/en/c-k/SS-24E06-TG-5-(P)/CKN10394-ND/2747191) | 9 | $7.56 | $0.84 | $0.84
IC REG LINEAR 3.3V 150MA SOT23-5 | U1 | 1 | Microchip Technology | MIC5317-3.3YM5-TR | DigiKey | MIC5317-3.3YM5-CT-ND (https://www.digikey.com/product-detail/en/microchip-technology/MIC5317-3.3YM5-TR/MIC5317-3.3YM5-CT-ND/7671939) | 50 | $6.70 | $0.13 | $0.13
IC MCU 16BIT 15.5KB FRAM 64LQFP | U2 | 1 | Texas Instruments | MSP430FR2033IPMR | DigiKey | 296-48617-1-ND (https://www.digikey.com/product-detail/en/texas-instruments/MSP430FR2033IPMR/296-48617-1-ND/8567661) | 7 | $18.20 | $2.60 | $2.60
LIGHT PIPE VERTICAL .450" ROUND |  | 16 | Bivar Inc. | VLP-450-R | DigiKey | 492-1347-ND (https://www.digikey.com/product-detail/en/bivar-inc/VLP-450-R/492-1347-ND/586475) | 100 | $29.23 | $0.29 | $4.68
HEX STNDFF M2.5X0.45 STEEL 10MM |  | 8 | Wurth Electronics Inc. | 971100151 | DigiKey | 732-10397-ND (https://www.digikey.com/product-detail/en/wurth-electronics-inc/971100151/732-10397-ND/6174616) | 50 | $19.80 | $0.40 | $3.17
HEX SPACER M2.5X0.45 STEEL 18MM |  | 8 | Wurth Electronics Inc. | 970180151 | DigiKey | 732-10586-ND (https://www.digikey.com/product-detail/en/wurth-electronics-inc/970180151/732-10586-ND/6174806) | 50 | $22.88 | $0.46 | $3.66
LED Display Lens |  | 2 | Hammond Manufacturing | 1593SIR10 | DigiKey | HM889-ND (https://www.digikey.com/product-detail/en/hammond-manufacturing/1593SIR10/HM889-ND/409899) | 5 | $2.58 | $0.52 | $1.03
BASE CONVERT MAIN PCB |  | 1 | JLCPCB |  | JLCPCB |  | 10 | $12.19 | $1.22 | $1.22
BASE CONVERT FRONT PCB |  | 1 | JLCPCB |  | JLCPCB |  | 10 | $9.19 | $0.92 | $0.92
BASE CONVERT BACK PCB |  | 1 | JLCPCB |  | JLCPCB |  | 10 | $12.19 | $1.22 | $1.22
Button Head Hex Drive Screw M2.5 x 5mm Long |  | 16 | McMaster-Carr | 94500A212 | McMaster-Carr |  | 100 | $11.66 | $0.12 | $1.87
Flat Head Phillips M1.6 x 6mm Long |  | 2 | McMaster-Carr | 92010A782 | McMaster-Carr |  | 100 | $8.58 | $0.09 | $0.17
Hex Nut M1.6 x 0.35mm |  | 2 | McMaster-Carr | 90591A109 | McMaster-Carr |  | 50 | $8.76 | $0.18 | $0.35
Washer M1.6 |  | 2 | McMaster-Carr | 93475A190 | McMaster-Carr |  | 100 | $2.27 | $0.02 | $0.05
 |  |  |  |  |  |  |  |  |  | $44.11
Build Cost | $44.11
Markup Multiplyier | 2.5
Selling Price | $110.27
Shipping Cost | $3.68
Total Cost To Customer | $113.95
Tindie Fee 5% | $5.70
Payment Processing Fee 4% + $0.3 | $4.86
Tindie Dispersment | $103.40
Profit | $59.29

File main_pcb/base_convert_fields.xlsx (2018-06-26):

Refs | Description | Manufacture | Mfg Part Number | Package | datasheet | footprint | value
BT1 | HOLDER BATT 4-AA CELLS WIRE LDS | MPD (Memory Protection Devices) | BC4AAW | Wire | http://www.memoryprotectiondevices.com/datasheets/BC4AAW-datasheet.pdf | MPD:BC4AAW | 4 Cell AA Battery Clip
C1 | CAP CER 1UF 16V X7R 0805 | Samsung Electro-Mechanics | CL21B105KOFNNNG | 0805 | http://www.samsungsem.com/kr/support/product-search/mlcc/CL21B105KOFNNNG.jsp | Capacitors_SMD:C_0805 | 1uF
C2 | CAP CER 10UF 6.3V X5R 0805 | Samsung Electro-Mechanics | CL21A106KQFNNNG | 0805 | http://www.samsungsem.com/kr/support/product-search/mlcc/CL21A106KQFNNNG.jsp | Capacitors_SMD:C_0805 | 10uF
C3 | CAP CER 0.1UF 16V X7R 0805 | Samsung Electro-Mechanics | CL21B104KOANNNC | 0805 | http://www.samsungsem.com/kr/support/product-search/mlcc/CL21B104KOANNNC.jsp | Capacitors_SMD:C_0805 | 100nF
C4 | CAP CER 1UF 16V X7R 0805 | Samsung Electro-Mechanics | CL21B105KOFNNNG | 0805 | http://www.samsungsem.com/kr/support/product-search/mlcc/CL21B105KOFNNNG.jsp | Capacitors_SMD:C_0805 | 1uF
D1 | LED RED CLEAR 0805 SMD | Wurth Electronics Inc. | 150080RS75000 | 0805 | http://katalog.we-online.de/led/datasheet/150080RS75000.pdf | LightPipe_Bivar:LED_0805_LightPipe_VLP | BIT3
D10 | LED RED CLEAR 0805 SMD | Wurth Electronics Inc. | 150080RS75001 | 0805 | http://katalog.we-online.de/led/datasheet/150080RS75000.pdf | LightPipe_Bivar:LED_0805_LightPipe_VLP | BIT5
D11 | LED RED CLEAR 0805 SMD | Wurth Electronics Inc. | 150080RS75002 | 0805 | http://katalog.we-online.de/led/datasheet/150080RS75000.pdf | LightPipe_Bivar:LED_0805_LightPipe_VLP | BIT9
D12 | LED RED CLEAR 0805 SMD | Wurth Electronics Inc. | 150080RS75003 | 0805 | http://katalog.we-online.de/led/datasheet/150080RS75000.pdf | LightPipe_Bivar:LED_0805_LightPipe_VLP | BIT13
D13 | LED RED CLEAR 0805 SMD | Wurth Electronics Inc. | 150080RS75004 | 0805 | http://katalog.we-online.de/led/datasheet/150080RS75000.pdf | LightPipe_Bivar:LED_0805_LightPipe_VLP | BIT0
D14 | LED RED CLEAR 0805 SMD | Wurth Electronics Inc. | 150080RS75005 | 0805 | http://katalog.we-online.de/led/datasheet/150080RS75000.pdf | LightPipe_Bivar:LED_0805_LightPipe_VLP | BIT4
D15 | LED RED CLEAR 0805 SMD | Wurth Electronics Inc. | 150080RS75006 | 0805 | http://katalog.we-online.de/led/datasheet/150080RS75000.pdf | LightPipe_Bivar:LED_0805_LightPipe_VLP | BIT8
D16 | LED RED CLEAR 0805 SMD | Wurth Electronics Inc. | 150080RS75007 | 0805 | http://katalog.we-online.de/led/datasheet/150080RS75000.pdf | LightPipe_Bivar:LED_0805_LightPipe_VLP | BIT12
D2 | LED RED CLEAR 0805 SMD | Wurth Electronics Inc. | 150080RS75008 | 0805 | http://katalog.we-online.de/led/datasheet/150080RS75000.pdf | LightPipe_Bivar:LED_0805_LightPipe_VLP | BIT7
D3 | LED RED CLEAR 0805 SMD | Wurth Electronics Inc. | 150080RS75009 | 0805 | http://katalog.we-online.de/led/datasheet/150080RS75000.pdf | LightPipe_Bivar:LED_0805_LightPipe_VLP | BIT11
D4 | LED RED CLEAR 0805 SMD | Wurth Electronics Inc. | 150080RS75010 | 0805 | http://katalog.we-online.de/led/datasheet/150080RS75000.pdf | LightPipe_Bivar:LED_0805_LightPipe_VLP | BIT15
D5 | LED RED CLEAR 0805 SMD | Wurth Electronics Inc. | 150080RS75011 | 0805 | http://katalog.we-online.de/led/datasheet/150080RS75000.pdf | LightPipe_Bivar:LED_0805_LightPipe_VLP | BIT2
D6 | LED RED CLEAR 0805 SMD | Wurth Electronics Inc. | 150080RS75012 | 0805 | http://katalog.we-online.de/led/datasheet/150080RS75000.pdf | LightPipe_Bivar:LED_0805_LightPipe_VLP | BIT6
D7 | LED RED CLEAR 0805 SMD | Wurth Electronics Inc. | 150080RS75013 | 0805 | http://katalog.we-online.de/led/datasheet/150080RS75000.pdf | LightPipe_Bivar:LED_0805_LightPipe_VLP | BIT10
D8 | LED RED CLEAR 0805 SMD | Wurth Electronics Inc. | 150080RS75014 | 0805 | http://katalog.we-online.de/led/datasheet/150080RS75000.pdf | LightPipe_Bivar:LED_0805_LightPipe_VLP | BIT14
D9 | LED RED CLEAR 0805 SMD | Wurth Electronics Inc. | 150080RS75015 | 0805 | http://katalog.we-online.de/led/datasheet/150080RS75000.pdf | LightPipe_Bivar:LED_0805_LightPipe_VLP | BIT1
DS1 | LED 7-SEG 2DIGIT RED LC 0.28\" CA | Lite-On Inc. | LTD-2601WC | 10-DIP | https://media.digikey.com/pdf/Data%20Sheets/Lite-On%20PDFs/LTD-2601WC_11-14-00.pdf | Lite-On:Display_Lite-On_LTD-2601WC | LTD-2601WC
DS2 | LED 7-SEG 2DIGIT RED LC 0.28\" CA | Lite-On Inc. | LTD-2601WC | 10-DIP | https://media.digikey.com/pdf/Data%20Sheets/Lite-On%20PDFs/LTD-2601WC_11-14-00.pdf | Lite-On:Display_Lite-On_LTD-2601WC | LTD-2601WC
DS3 | LED 7-SEG 2DIGIT RED LC 0.28\" CA | Lite-On Inc. | LTD-2601WC | 10-DIP | https://media.digikey.com/pdf/Data%20Sheets/Lite-On%20PDFs/LTD-2601WC_11-14-00.pdf | Lite-On:Display_Lite-On_LTD-2601WC | LTD-2601WC
DS4 | LED 7-SEG 2DIGIT RED LC 0.28\" CA | Lite-On Inc. | LTD-2601WC | 10-DIP | https://media.digikey.com/pdf/Data%20Sheets/Lite-On%20PDFs/LTD-2601WC_11-14-00.pdf | Lite-On:Display_Lite-On_LTD-2601WC | LTD-2601WC
DS5 | LED 7-SEG 2DIGIT RED LC 0.28\" CA | Lite-On Inc. | LTD-2601WC | 10-DIP | https://media.digikey.com/pdf/Data%20Sheets/Lite-On%20PDFs/LTD-2601WC_11-14-00.pdf | Lite-On:Display_Lite-On_LTD-2601WC | LTD-2601WC
J1 |  |  |  |  |  | Pin_Headers:Pin_Header_Straight_1x04_Pitch2.54mm | ISP
J3 | CONN HEADER PH SIDE 2POS 2MM | JST Sales America Inc. | S2B-PH-K-S(LF)(SN) | 2.0mm Pin | http://www.jst-mfg.com/product/pdf/eng/ePH.pdf | Connectors_JST:JST_PH_S2B-PH-K_02x2.00mm_Angled | Vin
JP1 | RES SMD 0 OHM JUMPER 1/4W 1206 | Yageo | RC1206JR-070RL | 1206 | http://www.yageo.com/documents/recent/PYu-RC_Group_51_RoHS_L_9.pdf | Resistors_SMD:R_1206 | VTARG_EN
Q1 | MOSFET P-CH 20V 5.3A SOT-23 | Vishay Siliconix | SI2323DDS-T1-GE3 | SOT-23 | http://www.vishay.com/docs/64004/si2323dds.pdf | TO_SOT_Packages_SMD:SOT-23 | Q_PMOS_GSD
Q10 | TRANS PNP 40V 0.2A SOT25 | Nexperia USA Inc. | PMBT3906,237 | SOT-23 | https://assets.nexperia.com/documents/data-sheet/PMBT3906.pdf | TO_SOT_Packages_SMD:SOT-23 | Q_PNP_BEC
Q11 | TRANS PNP 40V 0.2A SOT23 | Nexperia USA Inc. | PMBT3906,235 | SOT-23 | https://assets.nexperia.com/documents/data-sheet/PMBT3906.pdf | TO_SOT_Packages_SMD:SOT-23 | Q_PNP_BEC
Q12 | TRANS PNP 40V 0.2A SOT24 | Nexperia USA Inc. | PMBT3906,236 | SOT-23 | https://assets.nexperia.com/documents/data-sheet/PMBT3906.pdf | TO_SOT_Packages_SMD:SOT-23 | Q_PNP_BEC
Q13 | TRANS PNP 40V 0.2A SOT25 | Nexperia USA Inc. | PMBT3906,237 | SOT-23 | https://assets.nexperia.com/documents/data-sheet/PMBT3906.pdf | TO_SOT_Packages_SMD:SOT-23 | Q_PNP_BEC
Q14 | TRANS PNP 40V 0.2A SOT26 | Nexperia USA Inc. | PMBT3906,238 | SOT-23 | https://assets.nexperia.com/documents/data-sheet/PMBT3906.pdf | TO_SOT_Packages_SMD:SOT-23 | Q_PNP_BEC
Q15 | TRANS PNP 40V 0.2A SOT27 | Nexperia USA Inc. | PMBT3906,239 | SOT-23 | https://assets.nexperia.com/documents/data-sheet/PMBT3906.pdf | TO_SOT_Packages_SMD:SOT-23 | Q_PNP_BEC
Q16 | TRANS PNP 40V 0.2A SOT28 | Nexperia USA Inc. | PMBT3906,240 | SOT-23 | https://assets.nexperia.com/documents/data-sheet/PMBT3906.pdf | TO_SOT_Packages_SMD:SOT-23 | Q_PNP_BEC
Q17 | TRANS PNP 40V 0.2A SOT29 | Nexperia USA Inc. | PMBT3906,241 | SOT-23 | https://assets.nexperia.com/documents/data-sheet/PMBT3906.pdf | TO_SOT_Packages_SMD:SOT-23 | Q_PNP_BEC
Q18 | TRANS PNP 40V 0.2A SOT23 | Nexperia USA Inc. | PMBT3906,235 | SOT-23 | https://assets.nexperia.com/documents/data-sheet/PMBT3906.pdf | TO_SOT_Packages_SMD:SOT-23 | Q_PNP_BEC
Q19 | TRANS PNP 40V 0.2A SOT23 | Nexperia USA Inc. | PMBT3906,235 | SOT-23 | https://assets.nexperia.com/documents/data-sheet/PMBT3906.pdf | TO_SOT_Packages_SMD:SOT-23 | Q_PNP_BEC
Q2 | TRANS PNP 40V 0.2A SOT23 | Nexperia USA Inc. | PMBT3906,235 | SOT-23 | https://assets.nexperia.com/documents/data-sheet/PMBT3906.pdf | TO_SOT_Packages_SMD:SOT-23 | Q_PNP_BEC
Q20 | TRANSISTOR, NPN, 40V, 0.2A, 100A | Taiwan Semiconductor Corporation | MMBT3904L RFG | SOT-23 | http://www.taiwansemi.com/products/datasheet/MMBT3904L_A15.pdf | TO_SOT_Packages_SMD:SOT-23 | Q_NPN_BEC
Q21 | TRANSISTOR, NPN, 40V, 0.2A, 100A | Taiwan Semiconductor Corporation | MMBT3904L RFG | SOT-23 | http://www.taiwansemi.com/products/datasheet/MMBT3904L_A15.pdf | TO_SOT_Packages_SMD:SOT-23 | Q_NPN_BEC
Q22 | TRANSISTOR, NPN, 40V, 0.2A, 100A | Taiwan Semiconductor Corporation | MMBT3904L RFG | SOT-23 | http://www.taiwansemi.com/products/datasheet/MMBT3904L_A15.pdf | TO_SOT_Packages_SMD:SOT-23 | Q_NPN_BEC
Q23 | TRANSISTOR, NPN, 40V, 0.2A, 100A | Taiwan Semiconductor Corporation | MMBT3904L RFG | SOT-23 | http://www.taiwansemi.com/products/datasheet/MMBT3904L_A15.pdf | TO_SOT_Packages_SMD:SOT-23 | Q_NPN_BEC
Q24 | TRANSISTOR, NPN, 40V, 0.2A, 100A | Taiwan Semiconductor Corporation | MMBT3904L RFG | SOT-23 | http://www.taiwansemi.com/products/datasheet/MMBT3904L_A15.pdf | TO_SOT_Packages_SMD:SOT-23 | Q_NPN_BEC
Q25 | TRANSISTOR, NPN, 40V, 0.2A, 100A | Taiwan Semiconductor Corporation | MMBT3904L RFG | SOT-23 | http://www.taiwansemi.com/products/datasheet/MMBT3904L_A15.pdf | TO_SOT_Packages_SMD:SOT-23 | Q_NPN_BEC
Q26 | TRANSISTOR, NPN, 40V, 0.2A, 100A | Taiwan Semiconductor Corporation | MMBT3904L RFG | SOT-23 | http://www.taiwansemi.com/products/datasheet/MMBT3904L_A15.pdf | TO_SOT_Packages_SMD:SOT-23 | Q_NPN_BEC
Q27 | TRANSISTOR, NPN, 40V, 0.2A, 100A | Taiwan Semiconductor Corporation | MMBT3904L RFG | SOT-23 | http://www.taiwansemi.com/products/datasheet/MMBT3904L_A15.pdf | TO_SOT_Packages_SMD:SOT-23 | Q_NPN_BEC
Q3 | TRANS PNP 40V 0.2A SOT24 | Nexperia USA Inc. | PMBT3906,236 | SOT-23 | https://assets.nexperia.com/documents/data-sheet/PMBT3906.pdf | TO_SOT_Packages_SMD:SOT-23 | Q_PNP_BEC
Q4 | TRANS PNP 40V 0.2A SOT26 | Nexperia USA Inc. | PMBT3906,238 | SOT-23 | https://assets.nexperia.com/documents/data-sheet/PMBT3906.pdf | TO_SOT_Packages_SMD:SOT-23 | Q_PNP_BEC
Q5 | TRANS PNP 40V 0.2A SOT27 | Nexperia USA Inc. | PMBT3906,239 | SOT-23 | https://assets.nexperia.com/documents/data-sheet/PMBT3906.pdf | TO_SOT_Packages_SMD:SOT-23 | Q_PNP_BEC
Q6 | TRANSISTOR, NPN, 40V, 0.2A, 100A | Taiwan Semiconductor Corporation | MMBT3904L RFG | SOT-23 | http://www.taiwansemi.com/products/datasheet/MMBT3904L_A15.pdf | TO_SOT_Packages_SMD:SOT-23 | Q_NPN_BEC
Q7 | TRANSISTOR, NPN, 40V, 0.2A, 100A | Taiwan Semiconductor Corporation | MMBT3904L RFG | SOT-23 | http://www.taiwansemi.com/products/datasheet/MMBT3904L_A15.pdf | TO_SOT_Packages_SMD:SOT-23 | Q_NPN_BEC
Q8 | TRANSISTOR, NPN, 40V, 0.2A, 100A | Taiwan Semiconductor Corporation | MMBT3904L RFG | SOT-23 | http://www.taiwansemi.com/products/datasheet/MMBT3904L_A15.pdf | TO_SOT_Packages_SMD:SOT-23 | Q_NPN_BEC
Q9 | TRANSISTOR, NPN, 40V, 0.2A, 100A | Taiwan Semiconductor Corporation | MMBT3904L RFG | SOT-23 | http://www.taiwansemi.com/products/datasheet/MMBT3904L_A15.pdf | TO_SOT_Packages_SMD:SOT-23 | Q_NPN_BEC
R1 | RES SMD 102K OHM 1% 1/10W 0603 | Rohm Semiconductor | MCR03ERTF1023 | 0603 | http://rohmfs.rohm.com/en/products/databook/datasheet/passive/resistor/chip_resistor/mcr_g.pdf | Resistors_SMD:R_0603 | 102k
R10 | RES SMD 150 OHM 5% 1/10W 0603 | Yageo | RC0603JR-07150RL | 0603 | http://www.yageo.com/documents/recent/PYu-RC_Group_51_RoHS_L_9.pdf | Resistors_SMD:R_0603 | 150
R11 | RES SMD 4.7K OHM 5% 1/10W 0603 | Panasonic Electronic Components | ERJ-3GEYJ472V | 0603 | http://industrial.panasonic.com/www-cgi/jvcr13pz.cgi?E+PZ+3+AOA0001+ERJ3GEYJ472V+7+WW | Resistors_SMD:R_0603 | 4.7k
R12 | RES SMD 4.7K OHM 5% 1/10W 0603 | Panasonic Electronic Components | ERJ-3GEYJ472V | 0603 | http://industrial.panasonic.com/www-cgi/jvcr13pz.cgi?E+PZ+3+AOA0001+ERJ3GEYJ472V+7+WW | Resistors_SMD:R_0603 | 4.7k
R13 | RES SMD 4.7K OHM 5% 1/10W 0603 | Panasonic Electronic Components | ERJ-3GEYJ472V | 0603 | http://industrial.panasonic.com/www-cgi/jvcr13pz.cgi?E+PZ+3+AOA0001+ERJ3GEYJ472V+7+WW | Resistors_SMD:R_0603 | 4.7k
R14 | RES SMD 4.7K OHM 5% 1/10W 0603 | Panasonic Electronic Components | ERJ-3GEYJ472V | 0603 | http://industrial.panasonic.com/www-cgi/jvcr13pz.cgi?E+PZ+3+AOA0001+ERJ3GEYJ472V+7+WW | Resistors_SMD:R_0603 | 4.7k
R15 | RES SMD 4.7K OHM 5% 1/10W 0603 | Panasonic Electronic Components | ERJ-3GEYJ472V | 0603 | http://industrial.panasonic.com/www-cgi/jvcr13pz.cgi?E+PZ+3+AOA0001+ERJ3GEYJ472V+7+WW | Resistors_SMD:R_0603 | 4.7k
R16 | RES SMD 4.7K OHM 5% 1/10W 0603 | Panasonic Electronic Components | ERJ-3GEYJ472V | 0603 | http://industrial.panasonic.com/www-cgi/jvcr13pz.cgi?E+PZ+3+AOA0001+ERJ3GEYJ472V+7+WW | Resistors_SMD:R_0603 | 4.7k
R17 | RES SMD 4.7K OHM 5% 1/10W 0603 | Panasonic Electronic Components | ERJ-3GEYJ472V | 0603 | http://industrial.panasonic.com/www-cgi/jvcr13pz.cgi?E+PZ+3+AOA0001+ERJ3GEYJ472V+7+WW | Resistors_SMD:R_0603 | 4.7k
R18 | RES SMD 4.7K OHM 5% 1/10W 0603 | Panasonic Electronic Components | ERJ-3GEYJ472V | 0603 | http://industrial.panasonic.com/www-cgi/jvcr13pz.cgi?E+PZ+3+AOA0001+ERJ3GEYJ472V+7+WW | Resistors_SMD:R_0603 | 4.7k
R19 | RES SMD 4.7K OHM 5% 1/10W 0603 | Panasonic Electronic Components | ERJ-3GEYJ472V | 0603 | http://industrial.panasonic.com/www-cgi/jvcr13pz.cgi?E+PZ+3+AOA0001+ERJ3GEYJ472V+7+WW | Resistors_SMD:R_0603 | 4.7k
R2 | RES SMD 25.5K OHM 1% 1/10W 0603 | Rohm Semiconductor | MCR03ERTF2552 | 0603 | http://rohmfs.rohm.com/en/products/databook/datasheet/passive/resistor/chip_resistor/mcr_g.pdf | Resistors_SMD:R_0603 | 25.5k
R20 | RES SMD 4.7K OHM 5% 1/10W 0603 | Panasonic Electronic Components | ERJ-3GEYJ472V | 0603 | http://industrial.panasonic.com/www-cgi/jvcr13pz.cgi?E+PZ+3+AOA0001+ERJ3GEYJ472V+7+WW | Resistors_SMD:R_0603 | 4.7k
R21 | RES SMD 4.7K OHM 5% 1/10W 0603 | Panasonic Electronic Components | ERJ-3GEYJ472V | 0603 | http://industrial.panasonic.com/www-cgi/jvcr13pz.cgi?E+PZ+3+AOA0001+ERJ3GEYJ472V+7+WW | Resistors_SMD:R_0603 | 4.7k
R22 | RES SMD 4.7K OHM 5% 1/10W 0603 | Panasonic Electronic Components | ERJ-3GEYJ472V | 0603 | http://industrial.panasonic.com/www-cgi/jvcr13pz.cgi?E+PZ+3+AOA0001+ERJ3GEYJ472V+7+WW | Resistors_SMD:R_0603 | 4.7k
R23 | RES SMD 4.7K OHM 5% 1/10W 0603 | Panasonic Electronic Components | ERJ-3GEYJ472V | 0603 | http://industrial.panasonic.com/www-cgi/jvcr13pz.cgi?E+PZ+3+AOA0001+ERJ3GEYJ472V+7+WW | Resistors_SMD:R_0603 | 4.7k
R24 | RES SMD 4.7K OHM 5% 1/10W 0603 | Panasonic Electronic Components | ERJ-3GEYJ472V | 0603 | http://industrial.panasonic.com/www-cgi/jvcr13pz.cgi?E+PZ+3+AOA0001+ERJ3GEYJ472V+7+WW | Resistors_SMD:R_0603 | 4.7k
R25 | RES SMD 150 OHM 5% 1/10W 0603 | Yageo | RC0603JR-07150RL | 0603 | http://www.yageo.com/documents/recent/PYu-RC_Group_51_RoHS_L_9.pdf | Resistors_SMD:R_0603 | 150
R26 | RES SMD 150 OHM 5% 1/10W 0603 | Yageo | RC0603JR-07150RL | 0603 | http://www.yageo.com/documents/recent/PYu-RC_Group_51_RoHS_L_9.pdf | Resistors_SMD:R_0603 | 150
R27 | RES SMD 150 OHM 5% 1/10W 0603 | Yageo | RC0603JR-07150RL | 0603 | http://www.yageo.com/documents/recent/PYu-RC_Group_51_RoHS_L_9.pdf | Resistors_SMD:R_0603 | 150
R28 | RES SMD 150 OHM 5% 1/10W 0603 | Yageo | RC0603JR-07150RL | 0603 | http://www.yageo.com/documents/recent/PYu-RC_Group_51_RoHS_L_9.pdf | Resistors_SMD:R_0603 | 150
R29 | RES SMD 150 OHM 5% 1/10W 0603 | Yageo | RC0603JR-07150RL | 0603 | http://www.yageo.com/documents/recent/PYu-RC_Group_51_RoHS_L_9.pdf | Resistors_SMD:R_0603 | 150
R3 | RES SMD 4.7K OHM 5% 1/10W 0603 | Panasonic Electronic Components | ERJ-3GEYJ472V | 0603 | http://industrial.panasonic.com/www-cgi/jvcr13pz.cgi?E+PZ+3+AOA0001+ERJ3GEYJ472V+7+WW | Resistors_SMD:R_0603 | 4.7k
R30 | RES SMD 150 OHM 5% 1/10W 0603 | Yageo | RC0603JR-07150RL | 0603 | http://www.yageo.com/documents/recent/PYu-RC_Group_51_RoHS_L_9.pdf | Resistors_SMD:R_0603 | 150
R31 | RES SMD 150 OHM 5% 1/10W 0603 | Yageo | RC0603JR-07150RL | 0603 | http://www.yageo.com/documents/recent/PYu-RC_Group_51_RoHS_L_9.pdf | Resistors_SMD:R_0603 | 150
R32 | RES SMD 150 OHM 5% 1/10W 0603 | Yageo | RC0603JR-07150RL | 0603 | http://www.yageo.com/documents/recent/PYu-RC_Group_51_RoHS_L_9.pdf | Resistors_SMD:R_0603 | 150
R33 | RES SMD 4.7K OHM 5% 1/10W 0603 | Panasonic Electronic Components | ERJ-3GEYJ472V | 0603 | http://industrial.panasonic.com/www-cgi/jvcr13pz.cgi?E+PZ+3+AOA0001+ERJ3GEYJ472V+7+WW | Resistors_SMD:R_0603 | 4.7k
R34 | RES SMD 4.7K OHM 5% 1/10W 0603 | Panasonic Electronic Components | ERJ-3GEYJ472V | 0603 | http://industrial.panasonic.com/www-cgi/jvcr13pz.cgi?E+PZ+3+AOA0001+ERJ3GEYJ472V+7+WW | Resistors_SMD:R_0603 | 4.7k
R35 | RES SMD 4.7K OHM 5% 1/10W 0603 | Panasonic Electronic Components | ERJ-3GEYJ472V | 0603 | http://industrial.panasonic.com/www-cgi/jvcr13pz.cgi?E+PZ+3+AOA0001+ERJ3GEYJ472V+7+WW | Resistors_SMD:R_0603 | 4.7k
R36 | RES SMD 4.7K OHM 5% 1/10W 0603 | Panasonic Electronic Components | ERJ-3GEYJ472V | 0603 | http://industrial.panasonic.com/www-cgi/jvcr13pz.cgi?E+PZ+3+AOA0001+ERJ3GEYJ472V+7+WW | Resistors_SMD:R_0603 | 4.7k
R37 | RES SMD 4.7K OHM 5% 1/10W 0603 | Panasonic Electronic Components | ERJ-3GEYJ472V | 0603 | http://industrial.panasonic.com/www-cgi/jvcr13pz.cgi?E+PZ+3+AOA0001+ERJ3GEYJ472V+7+WW | Resistors_SMD:R_0603 | 4.7k
R38 | RES SMD 4.7K OHM 5% 1/10W 0603 | Panasonic Electronic Components | ERJ-3GEYJ472V | 0603 | http://industrial.panasonic.com/www-cgi/jvcr13pz.cgi?E+PZ+3+AOA0001+ERJ3GEYJ472V+7+WW | Resistors_SMD:R_0603 | 4.7k
R39 | RES SMD 4.7K OHM 5% 1/10W 0603 | Panasonic Electronic Components | ERJ-3GEYJ472V | 0603 | http://industrial.panasonic.com/www-cgi/jvcr13pz.cgi?E+PZ+3+AOA0001+ERJ3GEYJ472V+7+WW | Resistors_SMD:R_0603 | 4.7k
R4 | RES SMD 4.7K OHM 5% 1/10W 0603 | Panasonic Electronic Components | ERJ-3GEYJ472V | 0603 | http://industrial.panasonic.com/www-cgi/jvcr13pz.cgi?E+PZ+3+AOA0001+ERJ3GEYJ472V+7+WW | Resistors_SMD:R_0603 | 4.7k
R40 | RES SMD 4.7K OHM 5% 1/10W 0603 | Panasonic Electronic Components | ERJ-3GEYJ472V | 0603 | http://industrial.panasonic.com/www-cgi/jvcr13pz.cgi?E+PZ+3+AOA0001+ERJ3GEYJ472V+7+WW | Resistors_SMD:R_0603 | 4.7k
R5 | RES SMD 4.7K OHM 5% 1/10W 0603 | Panasonic Electronic Components | ERJ-3GEYJ472V | 0603 | http://industrial.panasonic.com/www-cgi/jvcr13pz.cgi?E+PZ+3+AOA0001+ERJ3GEYJ472V+7+WW | Resistors_SMD:R_0603 | 4.7k
R6 | RES SMD 4.7K OHM 5% 1/10W 0603 | Panasonic Electronic Components | ERJ-3GEYJ472V | 0603 | http://industrial.panasonic.com/www-cgi/jvcr13pz.cgi?E+PZ+3+AOA0001+ERJ3GEYJ472V+7+WW | Resistors_SMD:R_0603 | 4.7k
R7 | RES SMD 150 OHM 5% 1/10W 0603 | Yageo | RC0603JR-07150RL | 0603 | http://www.yageo.com/documents/recent/PYu-RC_Group_51_RoHS_L_9.pdf | Resistors_SMD:R_0603 | 150
R8 | RES SMD 150 OHM 5% 1/10W 0603 | Yageo | RC0603JR-07150RL | 0603 | http://www.yageo.com/documents/recent/PYu-RC_Group_51_RoHS_L_9.pdf | Resistors_SMD:R_0603 | 150
R9 | RES SMD 150 OHM 5% 1/10W 0603 | Yageo | RC0603JR-07150RL | 0603 | http://www.yageo.com/documents/recent/PYu-RC_Group_51_RoHS_L_9.pdf | Resistors_SMD:R_0603 | 150
SW1 | SWITCH SLIDE DP4T 300MA 30V | C&K | SS-24E06-TG 5 (P) | PC Pin | https://media.digikey.com/pdf/Data%20Sheets/C&K/SS-24E06-TG_5_(P).pdf | Switch_CK:DP4T_SS-24E06-TG5P | SELECT
SW10 | SWITCH TACTILE SPST-NO 0.05A 12V | C&K | PTS645SK13SMTR92LFS | SMT | https://www.ckswitches.com/media/1471/pts645.pdf | Switch_CK:CK_PTS645_6mm_SMD | 1
SW11 | SWITCH TACTILE SPST-NO 0.05A 12V | C&K | PTS645SK13SMTR92LFS | SMT | https://www.ckswitches.com/media/1471/pts645.pdf | Switch_CK:CK_PTS645_6mm_SMD | 4
SW12 | SWITCH TACTILE SPST-NO 0.05A 12V | C&K | PTS645SK13SMTR92LFS | SMT | https://www.ckswitches.com/media/1471/pts645.pdf | Switch_CK:CK_PTS645_6mm_SMD | 7
SW13 | SWITCH TACTILE SPST-NO 0.05A 12V | C&K | PTS645SK13SMTR92LFS | SMT | https://www.ckswitches.com/media/1471/pts645.pdf | Switch_CK:CK_PTS645_6mm_SMD | A
SW14 | SWITCH TACTILE SPST-NO 0.05A 12V | C&K | PTS645SK13SMTR92LFS | SMT | https://www.ckswitches.com/media/1471/pts645.pdf | Switch_CK:CK_PTS645_6mm_SMD | CLEAR
SW15 | SWITCH TACTILE SPST-NO 0.05A 12V | C&K | PTS645SK13SMTR92LFS | SMT | https://www.ckswitches.com/media/1471/pts645.pdf | Switch_CK:CK_PTS645_6mm_SMD | B
SW16 | SWITCH TACTILE SPST-NO 0.05A 12V | C&K | PTS645SK13SMTR92LFS | SMT | https://www.ckswitches.com/media/1471/pts645.pdf | Switch_CK:CK_PTS645_6mm_SMD | C
SW17 | SWITCH TACTILE SPST-NO 0.05A 12V | C&K | PTS645SK13SMTR92LFS | SMT | https://www.ckswitches.com/media/1471/pts645.pdf | Switch_CK:CK_PTS645_6mm_SMD | D
SW18 | SWITCH TACTILE SPST-NO 0.05A 12V | C&K | PTS645SK13SMTR92LFS | SMT | https://www.ckswitches.com/media/1471/pts645.pdf | Switch_CK:CK_PTS645_6mm_SMD | E
SW2 | SWITCH TACTILE SPST-NO 0.05A 12V | C&K | PTS645SK13SMTR92LFS | SMT | https://www.ckswitches.com/media/1471/pts645.pdf | Switch_CK:CK_PTS645_6mm_SMD | 3
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

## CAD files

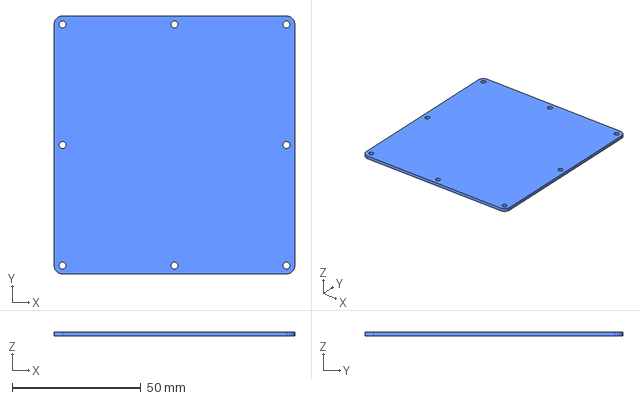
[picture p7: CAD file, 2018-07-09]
back_pannel_pcb/pcb_renders/back_panel_pcb1.step
93.3 x 100.0 x 1.60 mm
Pcb
Step_Models

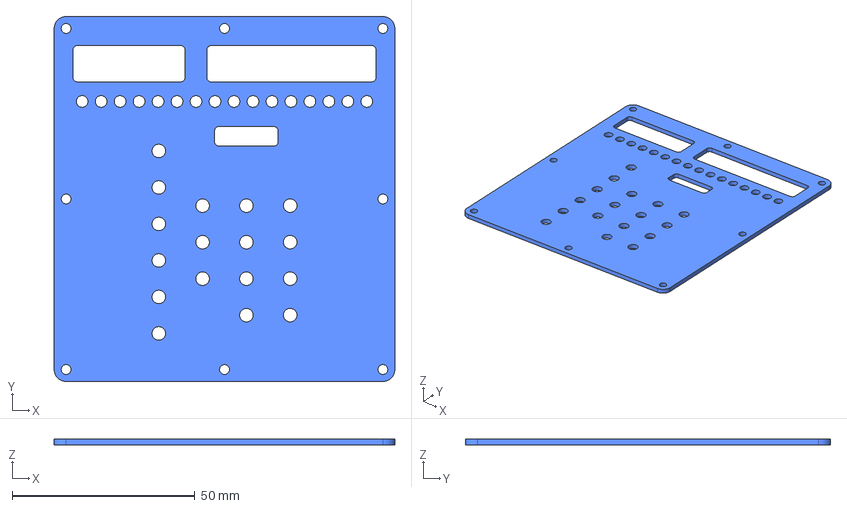
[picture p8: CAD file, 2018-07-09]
front_panel_pcb/pcb_renders/front_panel_pcb.step
93.3 x 100.0 x 1.60 mm
Pcb
Step_Models

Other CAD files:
back_pannel_pcb/pcb_renders/back_panel_pcb.FCStd
front_panel_pcb/pcb_renders/front_panel_pcb.FCStd

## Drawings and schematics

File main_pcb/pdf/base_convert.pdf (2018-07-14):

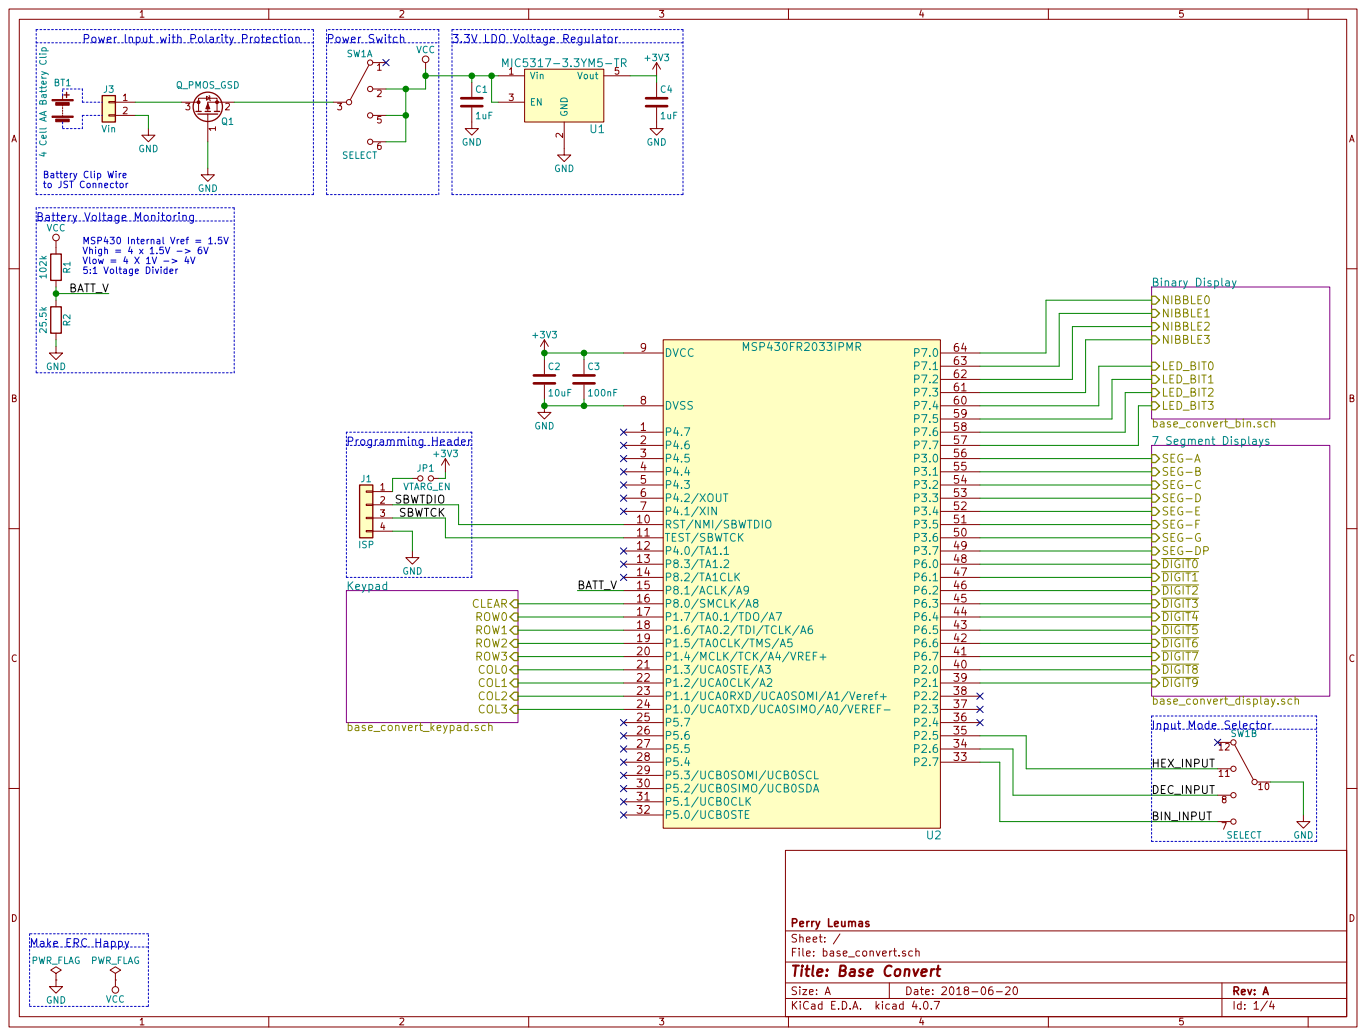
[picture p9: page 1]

to JST Connector Make ERC Happy

Input Mode Selector

File: base_convert.sch Sheet: / Perry Leumas

Id: 1/4 Title: Base Convert

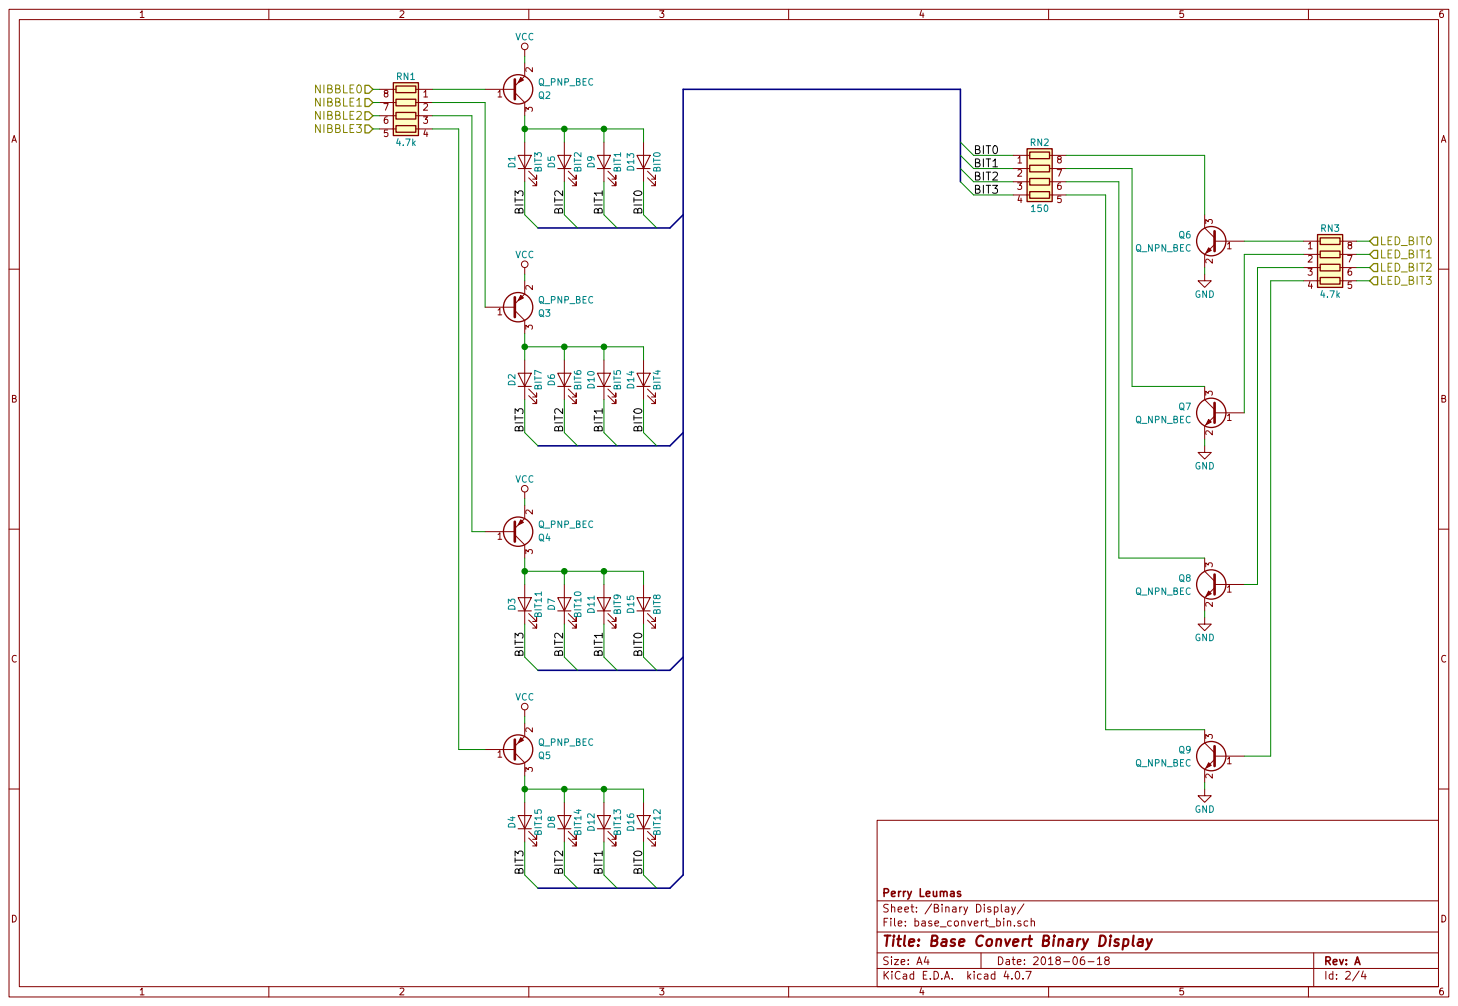
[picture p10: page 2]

Sheet: /Binary Display/
File: base_convert_bin.sch
Id: 2/4 Title: Base Convert Binary Display

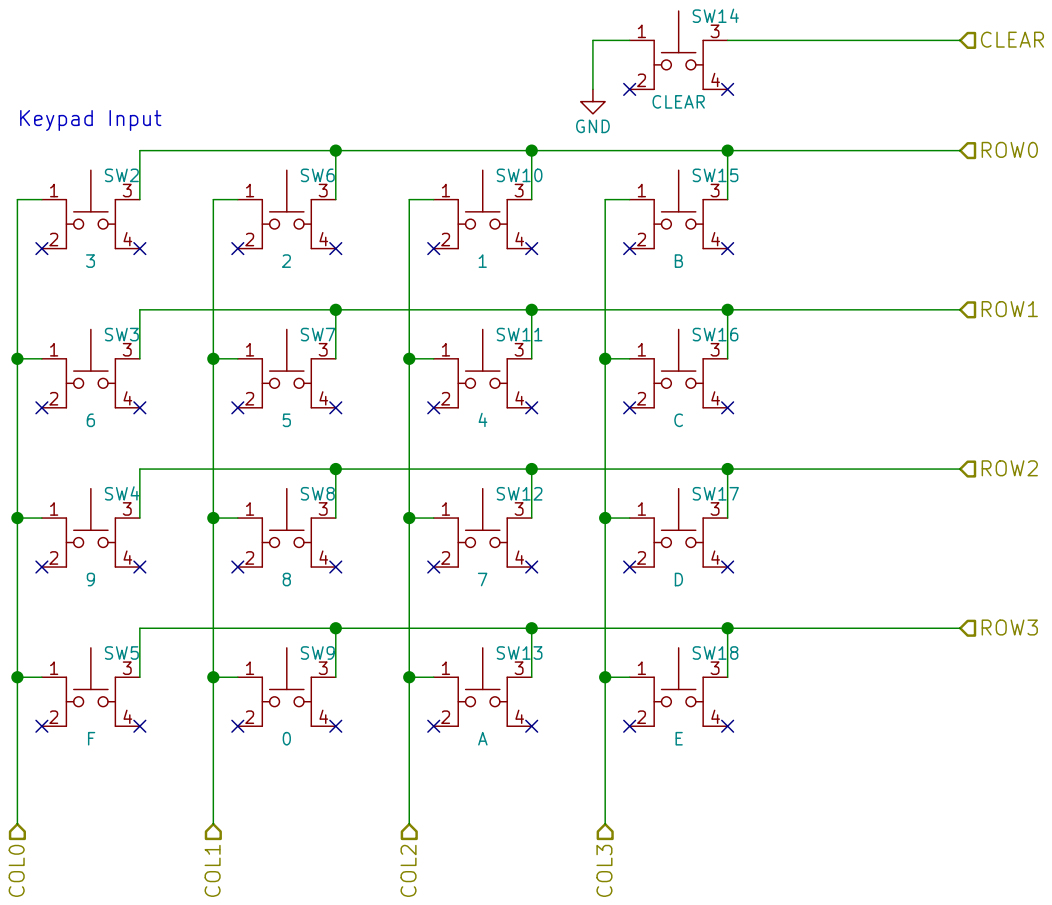
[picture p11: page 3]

4 SW14 CLEAR GND Keypad Input

Perry Leumas
Sheet: /Keypad/
File: base_convert_keypad.sch
Id: 3/4 Title: Base Convert Keypad

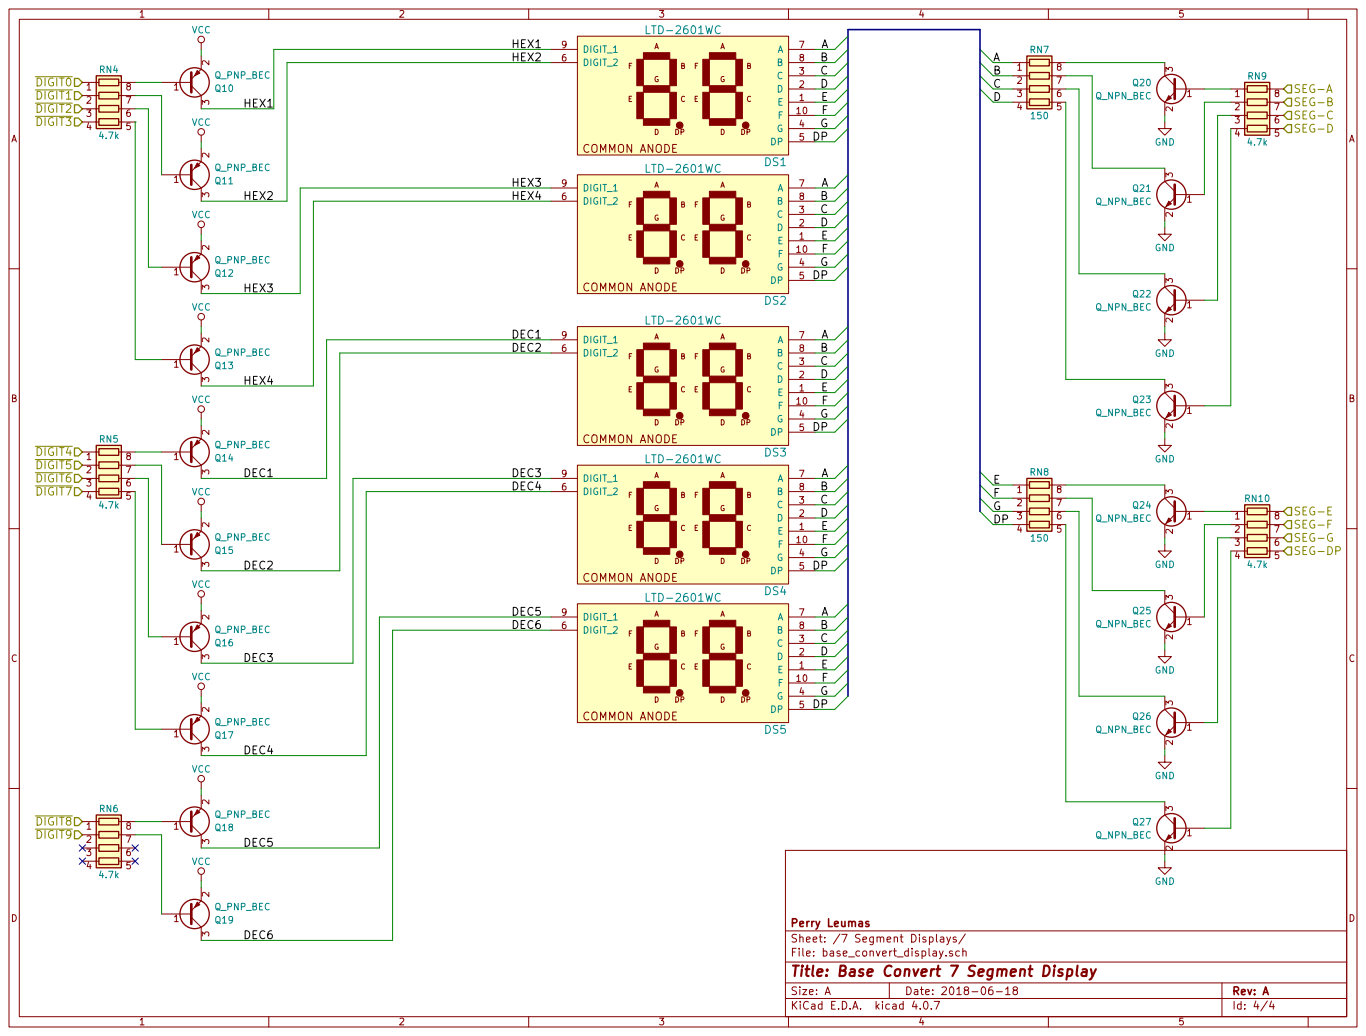
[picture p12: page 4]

Sheet: /7 Segment Displays/
File: base_convert_display.sch
Id: 4/4 Title: Base Convert 7 Segment Display

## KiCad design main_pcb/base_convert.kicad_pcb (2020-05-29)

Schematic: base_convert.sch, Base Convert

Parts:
BT1: 4 Cell AA Battery Clip; BC4AAW; Mfg Part Number BC4AAW
C1, C4: 1uF; C_0805; Mfg Part Number CL21B105KOFNNNG
C2: 10uF; C_0805; Mfg Part Number CL21A106MQFNNNE
C3: 100nF; C_0805; Mfg Part Number CL21B104KOANNNC
J1: ISP; PinHeader_1x04_P2.54mm_Horizontal; Mfg Part Number M20-9750446
J3: Vin; JST_PH_S2B-PH-K_02x2.00mm_Angled; Mfg Part Number S2B-PH-K-S(LF)(SN)
JP1: VTARG_EN; R_1206; Mfg Part Number RC1206JR-070RL
Q1: Q_PMOS_GSD; SOT-23; Mfg Part Number SI2323DDS-T1-GE3
R1: 102k; R_0603; Mfg Part Number MCR03ERTF1023
R2: 25.5k; R_0603; Mfg Part Number MCR03ERTF2552
SW1: SELECT; DP4T_SS-24E06-TG5P; Mfg Part Number SS-24E06-TG 5 (P)
U1: MIC5317-3.3YM5-TR; SOT-23-5; Mfg Part Number MIC5317-3.3YM5-TR
U2: MSP430FR2033IPMR; LQFP-64_10x10mm_Pitch0.5mm; Mfg Part Number MSP430FR2033IPMR

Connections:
+3V3: C2.1, C3.1, C4.1, JP1.2, U1.5, U2.9
/7 Segment Displays/SEG-A: U2.56; also elsewhere on the board
/7 Segment Displays/SEG-B: U2.55; also elsewhere on the board
/7 Segment Displays/SEG-C: U2.54; also elsewhere on the board
/7 Segment Displays/SEG-D: U2.53; also elsewhere on the board
/7 Segment Displays/SEG-DP: U2.49; also elsewhere on the board
/7 Segment Displays/SEG-E: U2.52; also elsewhere on the board
/7 Segment Displays/SEG-F: U2.51; also elsewhere on the board
/7 Segment Displays/SEG-G: U2.50; also elsewhere on the board
/7 Segment Displays/~DIGIT0: U2.48; also elsewhere on the board
/7 Segment Displays/~DIGIT1: U2.47; also elsewhere on the board
/7 Segment Displays/~DIGIT2: U2.46; also elsewhere on the board
/7 Segment Displays/~DIGIT3: U2.45; also elsewhere on the board
/7 Segment Displays/~DIGIT4: U2.44; also elsewhere on the board
/7 Segment Displays/~DIGIT5: U2.43; also elsewhere on the board
/7 Segment Displays/~DIGIT6: U2.42; also elsewhere on the board
/7 Segment Displays/~DIGIT7: U2.41; also elsewhere on the board
/7 Segment Displays/~DIGIT8: U2.40; also elsewhere on the board
/7 Segment Displays/~DIGIT9: U2.39; also elsewhere on the board
/BATT_V: R1.2, R2.1, U2.15
/BIN_INPUT: SW1.7 (D), U2.33
/Binary Display/LED_BIT0: U2.60; also elsewhere on the board
/Binary Display/LED_BIT1: U2.59; also elsewhere on the board
/Binary Display/LED_BIT2: U2.58; also elsewhere on the board
/Binary Display/LED_BIT3: U2.57; also elsewhere on the board
/Binary Display/NIBBLE0: U2.64; also elsewhere on the board
/Binary Display/NIBBLE1: U2.63; also elsewhere on the board
/Binary Display/NIBBLE2: U2.62; also elsewhere on the board
/Binary Display/NIBBLE3: U2.61; also elsewhere on the board
/DEC_INPUT: SW1.8 (C), U2.34
/HEX_INPUT: SW1.11 (B), U2.35
/Keypad/CLEAR: U2.16; also elsewhere on the board
/Keypad/COL0: U2.21; also elsewhere on the board
/Keypad/COL1: U2.22; also elsewhere on the board
/Keypad/COL2: U2.23; also elsewhere on the board
/Keypad/COL3: U2.24; also elsewhere on the board
/Keypad/ROW0: U2.17; also elsewhere on the board
/Keypad/ROW1: U2.18; also elsewhere on the board
/Keypad/ROW2: U2.19; also elsewhere on the board
/Keypad/ROW3: U2.20; also elsewhere on the board
/SBWTCK: J1.3, U2.11
/SBWTDIO: J1.2, U2.10
GND: C1.2, C2.2, C3.2, C4.2, J1.4, J3.2, Q1.1 (G), R2.2, SW1.10 (COM), U1.2, U2.8; also elsewhere on the board
unnamed: J1.1, JP1.1
unnamed: J3.1, Q1.3 (D)
unnamed: Q1.2 (S), SW1.3 (COM)
VCC: C1.1, R1.1, SW1.2 (B), SW1.5 (C), SW1.6 (D), U1.1, U1.3; also elsewhere on the board

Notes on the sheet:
Programming Header
3.3V LDO Voltage Regulator
Input Mode Selector
Power Input with Polarity Protection
Power Switch
MSP430 Internal Vref = 1.5V Vhigh = 4 x 1.5V -> 6V Vlow = 4 X 1V -> 4V 5:1 Voltage Divider
Battery Voltage Monitoring
Battery Clip Wire to JST Connector
Make ERC Happy

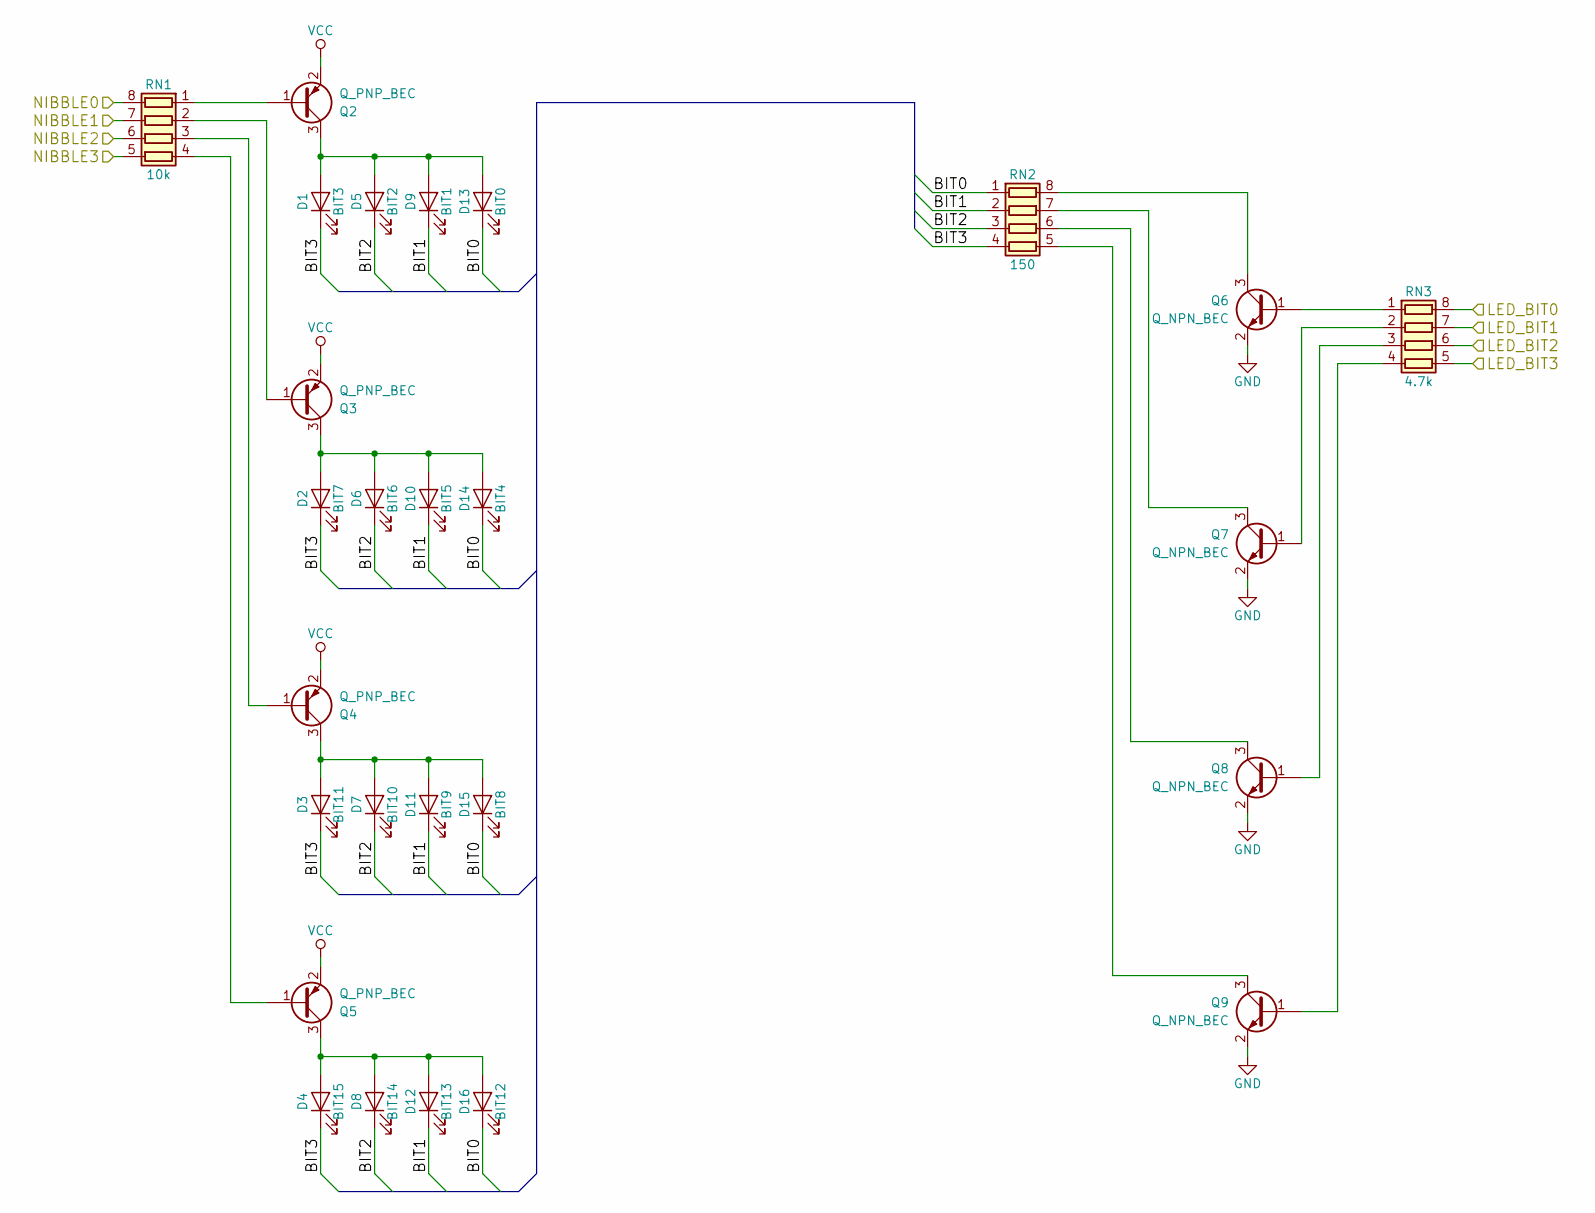
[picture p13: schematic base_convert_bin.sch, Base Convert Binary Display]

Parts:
D1: BIT3; LED_0805_LightPipe_VLP; Mfg Part Number 150080RS75000
D2: BIT7; LED_0805_LightPipe_VLP; Mfg Part Number 150080RS75000
D3: BIT11; LED_0805_LightPipe_VLP; Mfg Part Number 150080RS75000
D4: BIT15; LED_0805_LightPipe_VLP; Mfg Part Number 150080RS75000
D5: BIT2; LED_0805_LightPipe_VLP; Mfg Part Number 150080RS75000
D6: BIT6; LED_0805_LightPipe_VLP; Mfg Part Number 150080RS75000
D7: BIT10; LED_0805_LightPipe_VLP; Mfg Part Number 150080RS75000
D8: BIT14; LED_0805_LightPipe_VLP; Mfg Part Number 150080RS75000
D9: BIT1; LED_0805_LightPipe_VLP; Mfg Part Number 150080RS75000
D10: BIT5; LED_0805_LightPipe_VLP; Mfg Part Number 150080RS75000
D11: BIT9; LED_0805_LightPipe_VLP; Mfg Part Number 150080RS75000
D12: BIT13; LED_0805_LightPipe_VLP; Mfg Part Number 150080RS75000
D13: BIT0; LED_0805_LightPipe_VLP; Mfg Part Number 150080RS75000
D14: BIT4; LED_0805_LightPipe_VLP; Mfg Part Number 150080RS75000
D15: BIT8; LED_0805_LightPipe_VLP; Mfg Part Number 150080RS75000
D16: BIT12; LED_0805_LightPipe_VLP; Mfg Part Number 150080RS75000
Q2, Q3, Q4, Q5: Q_PNP_BEC; SOT-23; Mfg Part Number PDTA123ET,215
Q6, Q7, Q8, Q9: Q_NPN_BEC; SOT-23; Mfg Part Number MMBT3904L RFG
RN1: 10k; R_Array_Convex_4x1206; Mfg Part Number YC324-JK-0710KL
RN2: 150; R_Array_Convex_4x1206; Mfg Part Number MNR34J5ABJ151
RN3: 4.7k; R_Array_Convex_4x1206; Mfg Part Number MNR34J5ABJ562

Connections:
/Binary Display/BIT0: D13.1 (K), D14.1 (K), D15.1 (K), D16.1 (K), RN2.1 (R1.1)
/Binary Display/BIT1: D9.1 (K), D10.1 (K), D11.1 (K), D12.1 (K), RN2.2 (R2.1)
/Binary Display/BIT2: D5.1 (K), D6.1 (K), D7.1 (K), D8.1 (K), RN2.3 (R3.1)
/Binary Display/BIT3: D1.1 (K), D2.1 (K), D3.1 (K), D4.1 (K), RN2.4 (R4.1)
/Binary Display/LED_BIT0: RN3.8 (R1.2); also elsewhere on the board
/Binary Display/LED_BIT1: RN3.7 (R2.2); also elsewhere on the board
/Binary Display/LED_BIT2: RN3.6 (R3.2); also elsewhere on the board
/Binary Display/LED_BIT3: RN3.5 (R4.2); also elsewhere on the board
/Binary Display/NIBBLE0: RN1.8 (R1.2); also elsewhere on the board
/Binary Display/NIBBLE1: RN1.7 (R2.2); also elsewhere on the board
/Binary Display/NIBBLE2: RN1.6 (R3.2); also elsewhere on the board
/Binary Display/NIBBLE3: RN1.5 (R4.2); also elsewhere on the board
GND: Q6.2 (E), Q7.2 (E), Q8.2 (E), Q9.2 (E); also elsewhere on the board
unnamed: D1.2 (A), D5.2 (A), D9.2 (A), D13.2 (A), Q2.3 (C)
unnamed: D2.2 (A), D6.2 (A), D10.2 (A), D14.2 (A), Q3.3 (C)
unnamed: D3.2 (A), D7.2 (A), D11.2 (A), D15.2 (A), Q4.3 (C)
unnamed: D4.2 (A), D8.2 (A), D12.2 (A), D16.2 (A), Q5.3 (C)
unnamed: Q2.1 (B), RN1.1 (R1.1)
unnamed: Q3.1 (B), RN1.2 (R2.1)
unnamed: Q4.1 (B), RN1.3 (R3.1)
unnamed: Q5.1 (B), RN1.4 (R4.1)
unnamed: Q6.1 (B), RN3.1 (R1.1)
unnamed: Q6.3 (C), RN2.8 (R1.2)
unnamed: Q7.1 (B), RN3.2 (R2.1)
unnamed: Q7.3 (C), RN2.7 (R2.2)
unnamed: Q8.1 (B), RN3.3 (R3.1)
unnamed: Q8.3 (C), RN2.6 (R3.2)
unnamed: Q9.1 (B), RN3.4 (R4.1)
unnamed: Q9.3 (C), RN2.5 (R4.2)
VCC: Q2.2 (E), Q3.2 (E), Q4.2 (E), Q5.2 (E); also elsewhere on the board

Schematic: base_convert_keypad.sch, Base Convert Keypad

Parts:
SW2: 3; CK_PTS645_6mm_SMD; Mfg Part Number PTS645SK13SMTR92LFS
SW3: 6; CK_PTS645_6mm_SMD; Mfg Part Number PTS645SK13SMTR92LFS
SW4: 9; CK_PTS645_6mm_SMD; Mfg Part Number PTS645SK13SMTR92LFS
SW5: F; CK_PTS645_6mm_SMD; Mfg Part Number PTS645SK13SMTR92LFS
SW6: 2; CK_PTS645_6mm_SMD; Mfg Part Number PTS645SK13SMTR92LFS
SW7: 5; CK_PTS645_6mm_SMD; Mfg Part Number PTS645SK13SMTR92LFS
SW8: 8; CK_PTS645_6mm_SMD; Mfg Part Number PTS645SK13SMTR92LFS
SW9: 0; CK_PTS645_6mm_SMD; Mfg Part Number PTS645SK13SMTR92LFS
SW10: 1; CK_PTS645_6mm_SMD; Mfg Part Number PTS645SK13SMTR92LFS
SW11: 4; CK_PTS645_6mm_SMD; Mfg Part Number PTS645SK13SMTR92LFS
SW12: 7; CK_PTS645_6mm_SMD; Mfg Part Number PTS645SK13SMTR92LFS
SW13: A; CK_PTS645_6mm_SMD; Mfg Part Number PTS645SK13SMTR92LFS
SW14: CLEAR; CK_PTS645_6mm_SMD; Mfg Part Number PTS645SK13SMTR92LFS
SW15: B; CK_PTS645_6mm_SMD; Mfg Part Number PTS645SK13SMTR92LFS
SW16: C; CK_PTS645_6mm_SMD; Mfg Part Number PTS645SK13SMTR92LFS
SW17: D; CK_PTS645_6mm_SMD; Mfg Part Number PTS645SK13SMTR92LFS
SW18: E; CK_PTS645_6mm_SMD; Mfg Part Number PTS645SK13SMTR92LFS

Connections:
/Keypad/CLEAR: SW14.3; also elsewhere on the board
/Keypad/COL0: SW2.1, SW3.1, SW4.1, SW5.1; also elsewhere on the board
/Keypad/COL1: SW6.1, SW7.1, SW8.1, SW9.1; also elsewhere on the board
/Keypad/COL2: SW10.1, SW11.1, SW12.1, SW13.1; also elsewhere on the board
/Keypad/COL3: SW15.1, SW16.1, SW17.1, SW18.1; also elsewhere on the board
/Keypad/ROW0: SW2.3, SW6.3, SW10.3, SW15.3; also elsewhere on the board
/Keypad/ROW1: SW3.3, SW7.3, SW11.3, SW16.3; also elsewhere on the board
/Keypad/ROW2: SW4.3, SW8.3, SW12.3, SW17.3; also elsewhere on the board
/Keypad/ROW3: SW5.3, SW9.3, SW13.3, SW18.3; also elsewhere on the board
GND: SW14.1; also elsewhere on the board

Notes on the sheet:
Keypad Input

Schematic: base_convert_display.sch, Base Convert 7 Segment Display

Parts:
DS1, DS2, DS3, DS4, DS5: LTD-2601WC; Display_Lite-On_LTD-2601WC; Mfg Part Number LTD-2601WC
Q10, Q11, Q12, Q13, Q14, Q15, Q16, Q17, Q18, Q19: Q_PNP_BEC; SOT-23; Mfg Part Number PDTA123ET,215
Q20, Q21, Q22, Q23, Q24, Q25, Q26, Q27: Q_NPN_BEC; SOT-23; Mfg Part Number MMBT3904L RFG
RN4, RN5, RN6: 10k; R_Array_Convex_4x1206; Mfg Part Number YC324-JK-0710KL
RN7, RN8: 150; R_Array_Convex_4x1206; Mfg Part Number MNR34J5ABJ151
RN9, RN10: 4.7k; R_Array_Convex_4x1206; Mfg Part Number MNR34J5ABJ562

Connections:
/7 Segment Displays/A: DS1.7, DS2.7, DS3.7, DS4.7, DS5.7, RN7.1 (R1.1)
/7 Segment Displays/B: DS1.8, DS2.8, DS3.8, DS4.8, DS5.8, RN7.2 (R2.1)
/7 Segment Displays/C: DS1.3, DS2.3, DS3.3, DS4.3, DS5.3, RN7.3 (R3.1)
/7 Segment Displays/D: DS1.2, DS2.2, DS3.2, DS4.2, DS5.2, RN7.4 (R4.1)
/7 Segment Displays/DEC1: DS3.9, Q14.3 (C)
/7 Segment Displays/DEC2: DS3.6, Q15.3 (C)
/7 Segment Displays/DEC3: DS4.9, Q16.3 (C)
/7 Segment Displays/DEC4: DS4.6, Q17.3 (C)
/7 Segment Displays/DEC5: DS5.9, Q18.3 (C)
/7 Segment Displays/DEC6: DS5.6, Q19.3 (C)
/7 Segment Displays/DP: DS1.5, DS2.5, DS3.5, DS4.5, DS5.5, RN8.4 (R4.1)
/7 Segment Displays/E: DS1.1, DS2.1, DS3.1, DS4.1, DS5.1, RN8.1 (R1.1)
/7 Segment Displays/F: DS1.10, DS2.10, DS3.10, DS4.10, DS5.10, RN8.2 (R2.1)
/7 Segment Displays/G: DS1.4, DS2.4, DS3.4, DS4.4, DS5.4, RN8.3 (R3.1)
/7 Segment Displays/HEX1: DS1.9, Q10.3 (C)
/7 Segment Displays/HEX2: DS1.6, Q11.3 (C)
/7 Segment Displays/HEX3: DS2.9, Q12.3 (C)
/7 Segment Displays/HEX4: DS2.6, Q13.3 (C)
/7 Segment Displays/SEG-A: RN9.8 (R1.2); also elsewhere on the board
/7 Segment Displays/SEG-B: RN9.7 (R2.2); also elsewhere on the board
/7 Segment Displays/SEG-C: RN9.6 (R3.2); also elsewhere on the board
/7 Segment Displays/SEG-D: RN9.5 (R4.2); also elsewhere on the board
/7 Segment Displays/SEG-DP: RN10.5 (R4.2); also elsewhere on the board
/7 Segment Displays/SEG-E: RN10.8 (R1.2); also elsewhere on the board
/7 Segment Displays/SEG-F: RN10.7 (R2.2); also elsewhere on the board
/7 Segment Displays/SEG-G: RN10.6 (R3.2); also elsewhere on the board
/7 Segment Displays/~DIGIT0: RN4.1 (R1.1); also elsewhere on the board
/7 Segment Displays/~DIGIT1: RN4.2 (R2.1); also elsewhere on the board
/7 Segment Displays/~DIGIT2: RN4.3 (R3.1); also elsewhere on the board
/7 Segment Displays/~DIGIT3: RN4.4 (R4.1); also elsewhere on the board
/7 Segment Displays/~DIGIT4: RN5.1 (R1.1); also elsewhere on the board
/7 Segment Displays/~DIGIT5: RN5.2 (R2.1); also elsewhere on the board
/7 Segment Displays/~DIGIT6: RN5.3 (R3.1); also elsewhere on the board
/7 Segment Displays/~DIGIT7: RN5.4 (R4.1); also elsewhere on the board
/7 Segment Displays/~DIGIT8: RN6.1 (R1.1); also elsewhere on the board
/7 Segment Displays/~DIGIT9: RN6.2 (R2.1); also elsewhere on the board
GND: Q20.2 (E), Q21.2 (E), Q22.2 (E), Q23.2 (E), Q24.2 (E), Q25.2 (E), Q26.2 (E), Q27.2 (E); also elsewhere on the board
unnamed: Q10.1 (B), RN4.8 (R1.2)
unnamed: Q11.1 (B), RN4.7 (R2.2)
unnamed: Q12.1 (B), RN4.6 (R3.2)
unnamed: Q13.1 (B), RN4.5 (R4.2)
unnamed: Q14.1 (B), RN5.8 (R1.2)
unnamed: Q15.1 (B), RN5.7 (R2.2)
unnamed: Q16.1 (B), RN5.6 (R3.2)
unnamed: Q17.1 (B), RN5.5 (R4.2)
unnamed: Q18.1 (B), RN6.8 (R1.2)
unnamed: Q19.1 (B), RN6.7 (R2.2)
unnamed: Q20.1 (B), RN9.1 (R1.1)
unnamed: Q20.3 (C), RN7.8 (R1.2)
unnamed: Q21.1 (B), RN9.2 (R2.1)
unnamed: Q21.3 (C), RN7.7 (R2.2)
unnamed: Q22.1 (B), RN9.3 (R3.1)
unnamed: Q22.3 (C), RN7.6 (R3.2)
unnamed: Q23.1 (B), RN9.4 (R4.1)
unnamed: Q23.3 (C), RN7.5 (R4.2)
unnamed: Q24.1 (B), RN10.1 (R1.1)
unnamed: Q24.3 (C), RN8.8 (R1.2)
unnamed: Q25.1 (B), RN10.2 (R2.1)
unnamed: Q25.3 (C), RN8.7 (R2.2)
unnamed: Q26.1 (B), RN10.3 (R3.1)
unnamed: Q26.3 (C), RN8.6 (R3.2)
unnamed: Q27.1 (B), RN10.4 (R4.1)
unnamed: Q27.3 (C), RN8.5 (R4.2)
VCC: Q10.2 (E), Q11.2 (E), Q12.2 (E), Q13.2 (E), Q14.2 (E), Q15.2 (E), Q16.2 (E), Q17.2 (E), Q18.2 (E), Q19.2 (E); also elsewhere on the board

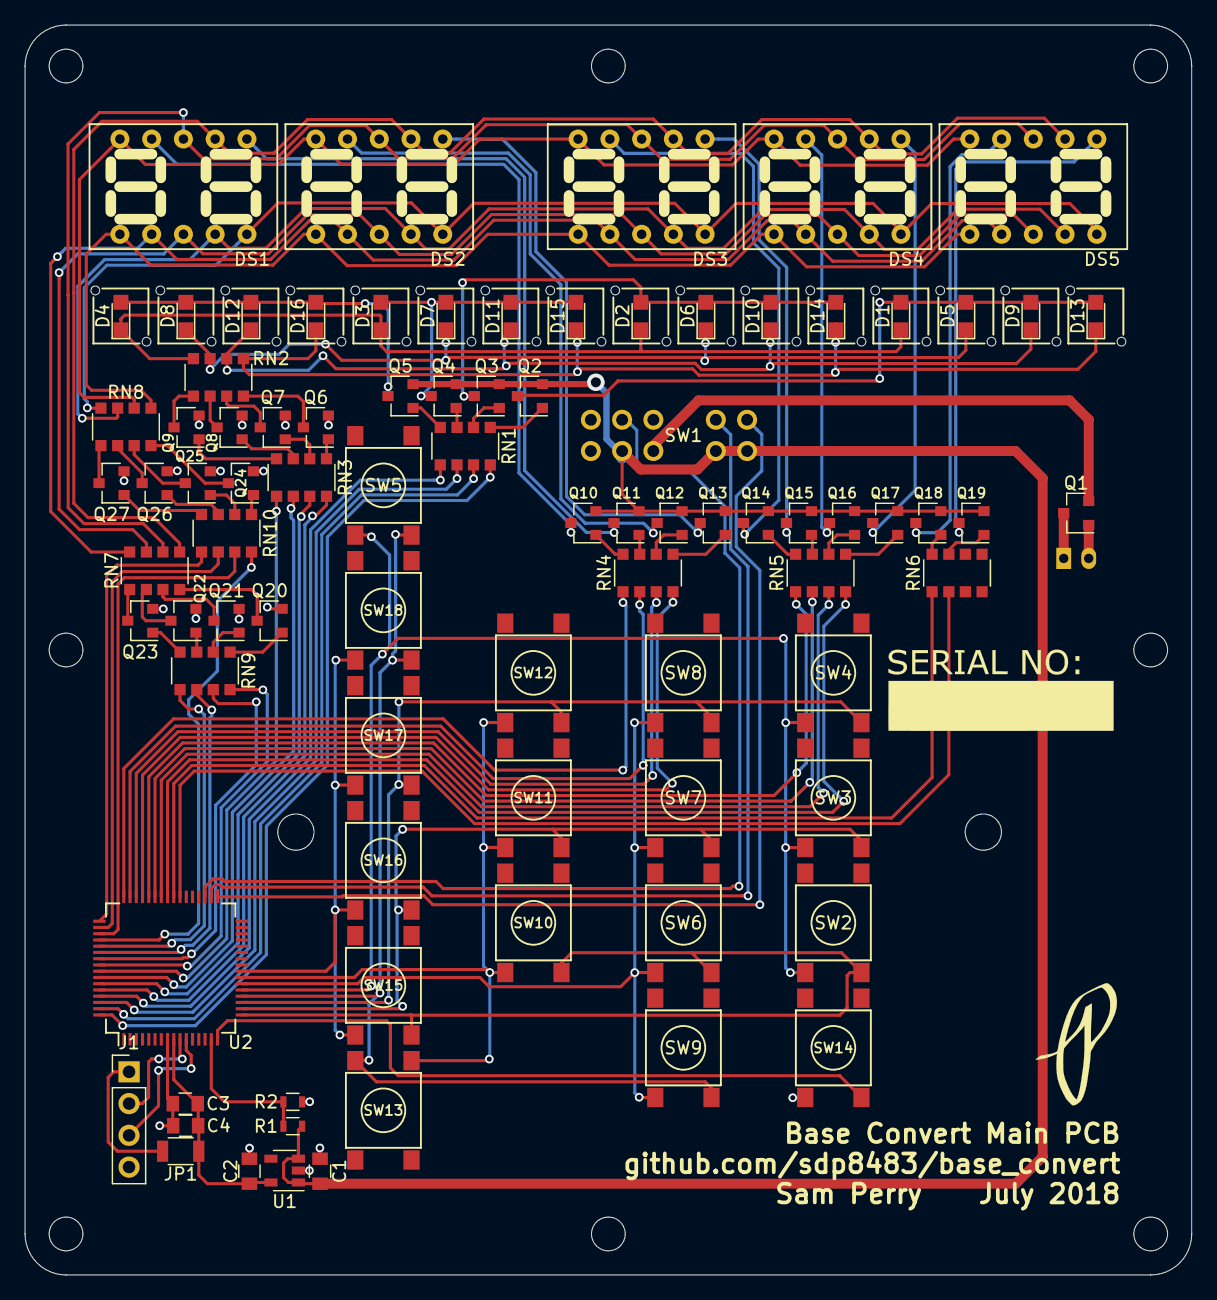
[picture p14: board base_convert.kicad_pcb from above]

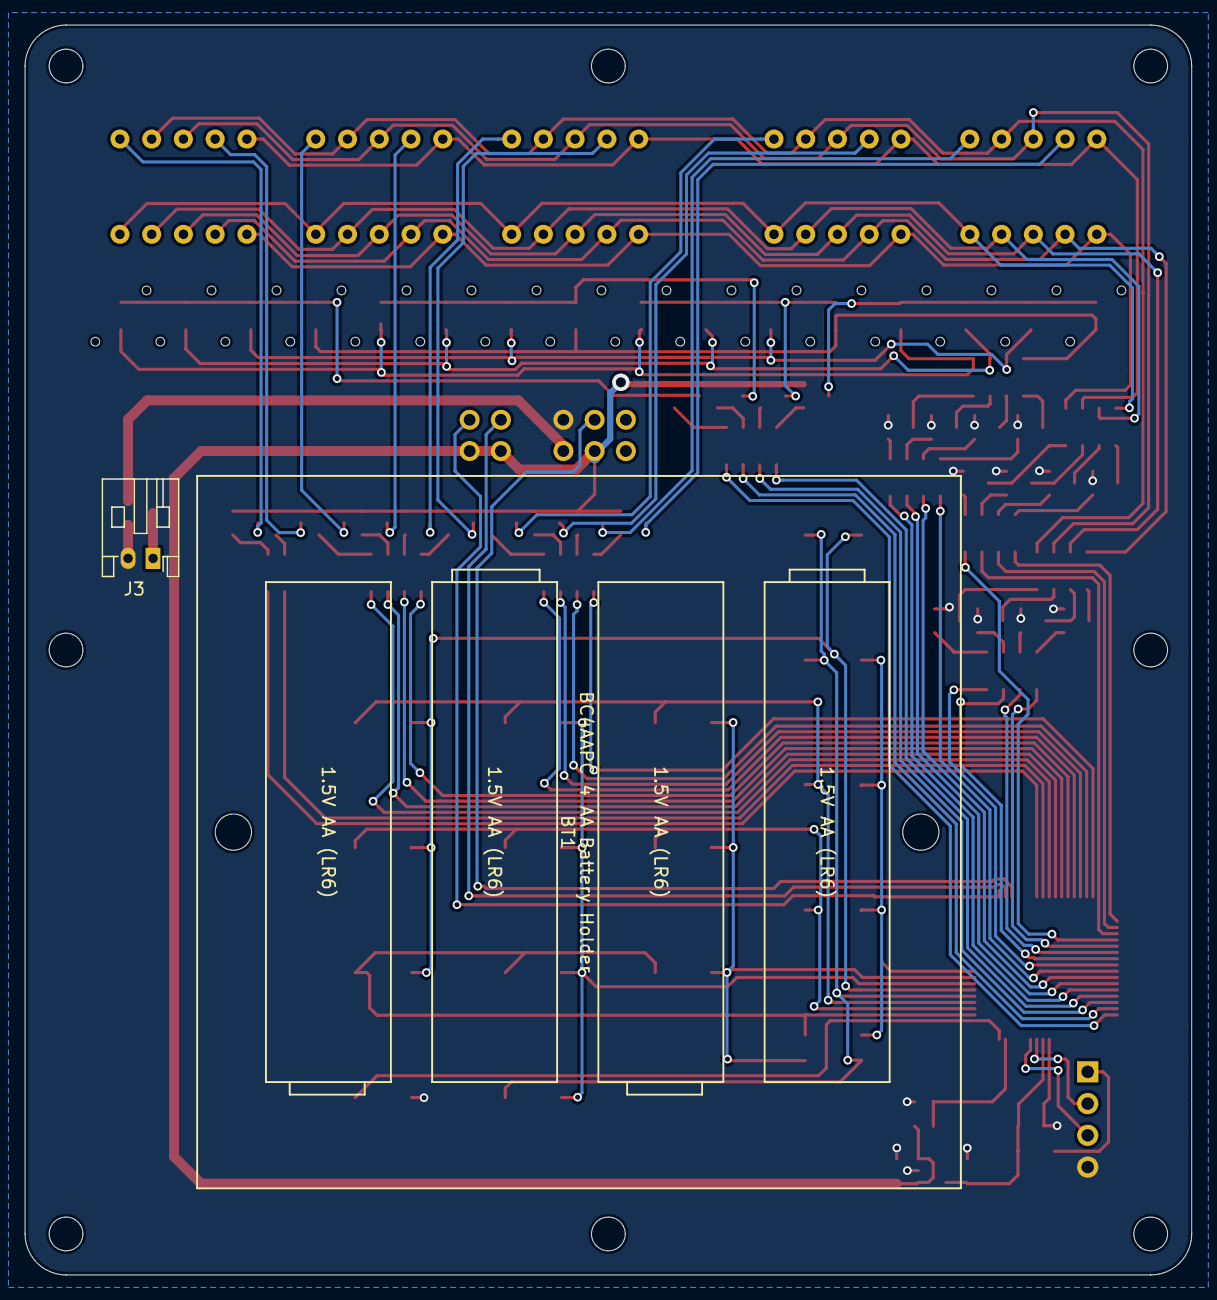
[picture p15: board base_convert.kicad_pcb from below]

Board: 2 copper layers, 93.3 x 100.0 mm, 88 parts (2 on the bottom side), 111 nets.

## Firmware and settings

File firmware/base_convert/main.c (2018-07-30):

/*
 * main.c
 *
 *  Created on: May 28, 2018
 *      Author: Sam
 */
#include <msp430.h>
#include <stdint.h>
#include "display.h"
#include "button.h"

#define REVA                                    // REV A remove separate BIN keypad

void main(void) {
    WDTCTL = WDTPW | WDTHOLD;                   // Stop watchdog timer

    dispSetup();                                // setup pins for HEX, DEC, and BIN display
    modeSetup();                                // setup pins for mode input slide switch
    clearSetup();                               // setup clear pin as input
    keySetup();                                 // setup DEC/HEX keypad

    PM5CTL0 &= ~LOCKLPM5;                       // Disable the GPIO power-on default high-impedance mode
                                                // to activate previously configured port settings

    __enable_interrupt();                       // Enable global interrupts

    TA0CCTL0 |= CCIE;                           // TACCR0 interrupt enabled
    TA0CCR0 = 1190;                             // 1190 should interrupt at ~840Hz
    TA0CTL = TASSEL__SMCLK | MC__UP;            // SMCLK, UP mode

    uint16_t num = 0x0;                         // this is the number that is being displayed, what it is all about

    for (;;){
        __bis_SR_register(LPM3_bits | GIE);     // Enter LPM3 w/ interrupt
        __no_operation();                       // For debugger

        // we have awaken from interrupt so time to do stuff
        dispBlank();                            // blank all the digits
        num = clearPoll(num);                   // clear input?

        switch (modeGet()) {
        case HEXMODE:
            num = keyPollHEX(num);              // new hex input?
            break;

        case DECMODE:
            num = keyPollDEC(num);              // new DEC input?
            break;

        case BINMODE:
            num = keyPollBIN(num);              // new BIN input?
            break;

        case NOMODE:
            //num = 0xFFFF;                       // no mode, display test?
            break;

        default:                                // should never get here
            break;
        }

        dispUpdate(num);                        // update the display

        TA0CTL ^= MC__UP;                       // toggle timer on
    } // end for(;;)

} // end main()

// Timer A0 interrupt service routine
#if defined(__TI_COMPILER_VERSION__) || defined(__IAR_SYSTEMS_ICC__)
#pragma vector = TIMER0_A0_VECTOR
__interrupt void Timer_A (void)
#elif defined(__GNUC__)
void __attribute__ ((interrupt(TIMER0_A0_VECTOR))) Timer_A (void)
#else
#error Compiler not supported!
#endif
{
    TA0CTL ^= MC__UP;                           // toggle timer off
    __bic_SR_register_on_exit(LPM3_bits);       // Exit LPM3
}

// WDT interrupt service routine
#if defined(__TI_COMPILER_VERSION__) || defined(__IAR_SYSTEMS_ICC__)
#pragma vector = WDT_VECTOR
__interrupt void WDT_ISR(void)
#else
#error Compiler not supported!
#endif
{
        WDTCTL = WDTPW + WDTHOLD;               // Stop WDT
        __bic_SR_register_on_exit(LPM3_bits);   // Exit LPM3
}

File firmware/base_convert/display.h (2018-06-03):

/*
 * display.h
 *
 *  Created on: May 28, 2018
 *      Author: Sam
 */

#ifndef DISPLAY_H_
#define DISPLAY_H_

#define DIGIT_MAX   9                           // if digit to update exceeds this, reset to zero

// 7 Segment HEX display
#define D0DIR   P6DIR                           // Digit0 direction
#define D0PORT  P6OUT                           // Digit0 port
#define D0PIN   BIT0                            // Digit0 pin
#define D1DIR   P6DIR
#define D1PORT  P6OUT
#define D1PIN   BIT1
#define D2DIR   P6DIR
#define D2PORT  P6OUT
#define D2PIN   BIT2
#define D3DIR   P6DIR
#define D3PORT  P6OUT
#define D3PIN   BIT3

// 7 Segment DEC display
#define D4DIR   P6DIR
#define D4PORT  P6OUT
#define D4PIN   BIT4
#define D5DIR   P6DIR
#define D5PORT  P6OUT
#define D5PIN   BIT5
#define D6DIR   P6DIR
#define D6PORT  P6OUT
#define D6PIN   BIT6
#define D7DIR   P6DIR
#define D7PORT  P6OUT
#define D7PIN   BIT7
#define D8DIR   P2DIR
#define D8PORT  P2OUT
#define D8PIN   BIT0
#define D8DIR   P2DIR
#define D8PORT  P2OUT
#define D9DIR   P2DIR
#define D9PORT  P2OUT
#define D9PIN   BIT1

// Segment pin defines
#define SEGDIR  P3DIR
#define SEGPORT P3OUT
#define SEG_A   BIT0
#define SEG_B   BIT1
#define SEG_C   BIT2
#define SEG_D   BIT3
#define SEG_E   BIT4
#define SEG_F   BIT5
#define SEG_G   BIT6
#define SEG_DP  BIT7
#define ALLSEG  SEG_A + SEG_B + SEG_C + SEG_D + SEG_E + SEG_F + SEG_G + SEG_DP

// Numeral segment defines
#define ZERO    SEG_A + SEG_B + SEG_C + SEG_D + SEG_E + SEG_F
#define ONE     SEG_B + SEG_C
#define TWO     SEG_A + SEG_B + SEG_G + SEG_E + SEG_D
#define THREE   SEG_A + SEG_B + SEG_C + SEG_D + SEG_G
#define FOUR    SEG_B + SEG_C + SEG_G + SEG_F
#define FIVE    SEG_A + SEG_F + SEG_G + SEG_C + SEG_D
#define SIX     SEG_A + SEG_F + SEG_G + SEG_C + SEG_D + SEG_E
#define SEVEN   SEG_A + SEG_B + SEG_C
#define EIGHT   SEG_A + SEG_B + SEG_C + SEG_D + SEG_E + SEG_F + SEG_G
#define NINE    SEG_A + SEG_B + SEG_C + SEG_D + SEG_F + SEG_G
#define HEX_A   SEG_A + SEG_B + SEG_C + SEG_E + SEG_F + SEG_G
#define HEX_B   SEG_C + SEG_D + SEG_E + SEG_F + SEG_G
#define HEX_C   SEG_A + SEG_D + SEG_E + SEG_F
#define HEX_D   SEG_B + SEG_C + SEG_D + SEG_E + SEG_G
#define HEX_E   SEG_A + SEG_D + SEG_E + SEG_F + SEG_G
#define HEX_F   SEG_A + SEG_E + SEG_F + SEG_G

// BIN display nibble defines
#define NDIR    P7DIR
#define NPORT   P7OUT
#define N0PIN   BIT0
#define N1PIN   BIT1
#define N2PIN   BIT2
#define N3PIN   BIT3

// BIN display bit defines
#define BPORT   P7OUT
#define BDIR    P7DIR
#define B0PIN   BIT4
#define B1PIN   BIT5
#define B2PIN   BIT6
#define B3PIN   BIT7

// BIN segment defines
#define B1      B0PIN
#define B2      B1PIN
#define B3      B1PIN + B0PIN
#define B4      B2PIN
#define B5      B2PIN + B0PIN
#define B6      B2PIN + B1PIN
#define B7      B2PIN + B1PIN + B0PIN
#define B8      B3PIN
#define B9      B3PIN + B0PIN
#define BA      B3PIN + B1PIN
#define BB      B3PIN + B1PIN + B0PIN
#define BC      B3PIN + B2PIN
#define BD      B3PIN + B2PIN + B0PIN
#define BE      B3PIN + B2PIN + B1PIN
#define BF      B3PIN + B2PIN + B1PIN + B0PIN

// prototype defines
void dispSetup(void);                           // setup pins for the HEX, DEC, and BIN displays
void dispBlank(void);                           // blank display, ready for next digit update
void dispUpdate(uint16_t num);                  // update display
uint8_t dispSegments(uint8_t value);            // return 7-segments based on value
uint8_t dispBin(uint8_t value);                 // return bin segments base on value

#endif /* DISPLAY_H_ */

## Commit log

2018-03-28 concept layout
    layout for initial concept photo. may not be actual components for final design
    [DA04-11SURKWA.step, LED_D3.0mm.step, base_convert.kicad_pcb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]
2018-04-14 perlimanary prototype render
    perlimanary prototype render complete
    [SW_SPST_FSMSM.fcstd, SW_SPST_FSMSM.step, base_convert.kicad_pcb]
2018-05-03 start schematic
    getting there
    [base_convert.sch, base_convert_display.sch, base_convert_uC.sch]
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2018-05-06 schematic captured, footprints complete
    [base_convert.sch, base_convert_bin.sch, base_convert_display.sch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]
2018-05-07 remove external pulldown resistors
    [base_convert_keypad.sch]
2018-05-11 update 7-segment display part number
    Due to mismatch of display face using a mix of 4 digit and 1 digit displays does not look good. Swtiching all displays to be made up of 2 digit 7-segment display. Decimal display will have extra unus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
    [base_convert.kicad_pcb, base_convert.sch, base_convert_bin.sch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]
2018-05-12 updated shema fields. Raplced tack switch with 4 pin footprint
    Using 4 pin tack switch to ease pcb layout connecitions. Also updated component fields in schema
    [base_convert.sch, base_convert_bin.sch, base_convert_display.sch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]
2018-05-15 Push and shove for the win!
    To Do: clean up.
    [base_convert.kicad_pcb, base_convert.sch, base_convert_bin.sch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]
2018-05-15 add header to break out 3 unsused pins just in case
    [base_convert.kicad_pcb, base_convert.sch, base_convert_bin.sch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]
2018-05-15 Silkscreen cleanup, add 3d models for render
    [DA04-11SURKWA.step, LED_D3.0mm.step, SW_SPST_FSMSM.fcstd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]
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2018-06-04 replaced __delay_cycles with WDT intervals
    NICE!
    [button.h, main.c]
2018-06-07 safe decimal input
    prevent integer overflow in decimal input mode. Also some code cleanup
    [button.h, main.c]
2018-06-16 fixed pnp to be common emitter
    [base_convert.sch, base_convert_bin.sch, base_convert_display.sch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]
2018-06-16 move clear button to keypad sheet
    [base_convert.sch, base_convert_keypad.sch]
2018-06-17 change led current limit resistor value
    [base_convert_bin.sch, base_convert_display.sch]
2018-06-17 change uC to MSP430FR2033, non lcd variant
    [base_convert.sch]
2018-06-17 update U1 datasheet link
    [base_convert.sch]
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2018-06-17 update msp430 symbol for cleaner schematic
    [base_convert.sch]
2018-06-17 modify batery monitor divider
    [base_convert.sch]
2018-06-18 renamed digit control lines
    [base_convert.sch, base_convert_display.sch]
2018-06-18 removed extra pin header
    [base_convert.sch]
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2018-06-18 add led light pipes
    [base_convert_bin.sch]
2018-06-18 update ldo to instock MIC5317
    [base_convert.sch, base_convert_bin.sch, base_convert_display.sch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]
2018-06-18 breakout port 5 to header
    [base_convert.sch, base_convert_bin.sch, base_convert_display.sch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]
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2018-06-18 update keypad switch footprint to smd
    [base_convert_keypad.sch]
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2018-06-19 update sheet title block
    [base_convert.sch, base_convert_bin.sch, base_convert_display.sch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]
2018-06-19 spaw reference so U1 is uC as in previous version
    [base_convert.sch]
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2018-06-19 change 7-seg to 7mm tall digits
    [base_convert_display.sch]
2018-06-21 battery clip change to wire connection
    [base_convert.sch]
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2018-06-22 remove extra gpio header
    [base_convert.sch]
2018-06-22 new pcb layout for v2, major component placement
    [base_convert.kicad_pcb]
2018-06-23 add slide switch 3d shape
    [base_convert.kicad_pcb]
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2018-06-25 add 7seg 3d model
    [base_convert.kicad_pcb]
2018-06-25 add tactile switch 3d model
    [base_convert.kicad_pcb]
2018-06-26 change keypad switch to longer actuator
    [base_convert.kicad_pcb, base_convert.sch, base_convert_display.sch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]
2018-06-26 change light pipe PN
    [base_convert.kicad_pcb]
2018-06-26 add 3d model for battery holder
    [base_convert.kicad_pcb]
2018-06-26 update all compoents with 3d models
    [base_convert.kicad_pcb]
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2018-06-27 Vtarg connect to 3v3 not Vcc
    [base_convert.sch, base_convert_bin.sch, base_convert_display.sch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]
2018-06-27 wire swap for easy layout
    [base_convert_keypad.sch]
2018-06-28 update display resistors to arrays
    [base_convert.sch, base_convert_bin.sch, base_convert_display.sch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]
2018-06-28 power ID numbers changed?
    [base_convert.sch, base_convert_bin.sch, base_convert_display.sch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]
2018-06-28 switch resitors to arrays
    [base_convert.kicad_pcb]
2018-06-29 mirror RN1 about y asix for easy layout
    [base_convert_bin.sch]
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2018-07-01 layout complete, requires cleanup
    [base_convert.kicad_pcb]
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2018-07-02 add JST connector 3d model
    [base_convert.kicad_pcb]
2018-07-04 create front panel pcb project
    [front_panel_pcb.sch]
2018-07-04 layout front panel binary display with silkscreen
    [front_panel_pcb.kicad_pcb]
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2018-07-04 layout front panel keypad with silkscreen
    [front_panel_pcb.kicad_pcb]
2018-07-04 selection switch front panel cutout and silk screen
    [front_panel_pcb.kicad_pcb]
2018-07-04 7seg front panel cutout and silkscreen
    [front_panel_pcb.kicad_pcb]
2018-07-04 shift lables above 7seg displays left 1.25 and up 0.2
    [front_panel_pcb.kicad_pcb]
2018-07-04 remove battery, there will be no screws on front panel
    [front_panel_pcb.kicad_pcb]
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2018-07-05 fix bad index of CUT OUT not having a layer
    [front_panel_pcb.kicad_pcb]
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2018-07-09 will not fit in battery clip mounting holes, head is too large
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2018-07-10 copper flood back and front, adjust some things
    [front_panel_pcb.kicad_pcb, front_panel_pcb.sch]
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2018-07-13 fix left and top board color
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2018-07-14 correct pnp part number
    [base_convert.sch, base_convert_bin.sch, base_convert_display.sch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]
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2018-07-30 missing break for case NOMODE
    [main.c]
2018-08-05 need to swap C4 and C2 on pcb
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2018-08-20 correct part number
    [base_convert.sch]
2018-08-20 correct LED part numbers
    [base_convert_bin.sch]
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
